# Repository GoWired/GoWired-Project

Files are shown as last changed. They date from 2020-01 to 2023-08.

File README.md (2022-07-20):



This is a repository for **GoWired**, RS485 & MySensors based, open source home automation hardware previously released at [openhardware.io](https://www.openhardware.io/user/2098#view=projects). Lately it took part in a successful **[crowdfunding campaign](https://www.crowdsupply.com/domatic/getwired)**. It is now available to buy at [Mouser](https://www2.mouser.com/Search/Refine?Keyword=getwired).

## Features
- MySensors library for communication through RS485 protocol,
- FOTW updates,
- Thermal and electrical security procedures,
- Easy configuration,
- Operating with ON/OFF receivers, roller shutters, dimmable LED tapes (white, RGB, RGBW),
- Buttons: long press and short press logic,
- Sensors: built-in current sensor and temperature sensor handling.

## Wiki
To learn more, have a look at our [wiki](https://github.com/feanor-anglin/GetWired-Project/wiki).

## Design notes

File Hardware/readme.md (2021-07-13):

All hardware schematics will be released here.

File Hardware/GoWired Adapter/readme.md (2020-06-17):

Gerber and BOM files of the Programming Adapter will be soon released here.

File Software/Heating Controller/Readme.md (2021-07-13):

Software from this folder can be used with any shield. 

This is a heating controller which is designed to control heating valves on the basis of readings from external thermometers. 
It can work with up to 8 sections. It is possible to set individual daytime temperature for every section. 
Nighttime, holiday time temperatures and hysteresis value are set for the whole module.

There are two operating methods:
- autonomous - in which the software switches outputs automatically, on the basis of comparing temperature readings with set points (it is only necessary to switch modes - day/night/holiday by an external controller)
- dependent - in which it is possible to switch outputs fron an external controller

Both methods can be switched during the controller's operation.

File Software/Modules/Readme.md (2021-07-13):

Software from this folder can be used with the following shields:
- 2SSR Shield
- RGBW Shield
- 4RelayDin Shield

It can be used for:
- Controlling lighting and other appliances (ON/OFF)
- Dimming lighting (12-24 V DC, white, RGB, RGBW)
- Controlling roller shutters (also by percentage)

Additional features
- Control board temperature (2SSR & RGBW)
- Control current (2SSR, RGBW & 4RelayDin)
- Read external thermometers: DHT22, SHT30 (2SSR, RGBW & 4RelayDin)
- Report temperature values to external Heating Controller (2SSR, RGBW & 4RelayDin)
- Read digital & analog inputs (2SSR, RGBW & 4RelayDin)
- Roller shutter auto calibration (2SSR)
- AVR watchdog

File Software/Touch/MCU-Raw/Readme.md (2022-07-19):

Firmware for Touch MCU with no wired communication functionality.

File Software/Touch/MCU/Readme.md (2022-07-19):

Firmware for Touch MCU with wired communication functionality.

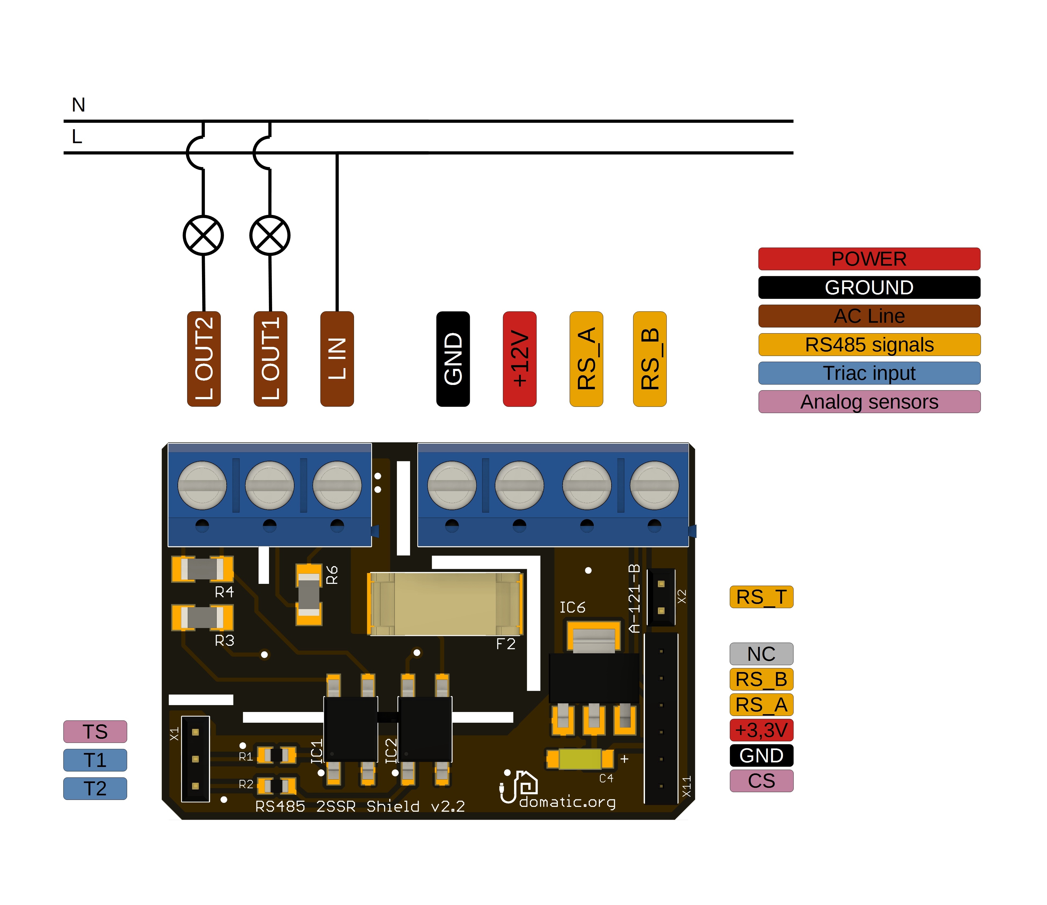
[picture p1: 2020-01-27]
Images/2SSR_Pinout_notitle.jpg

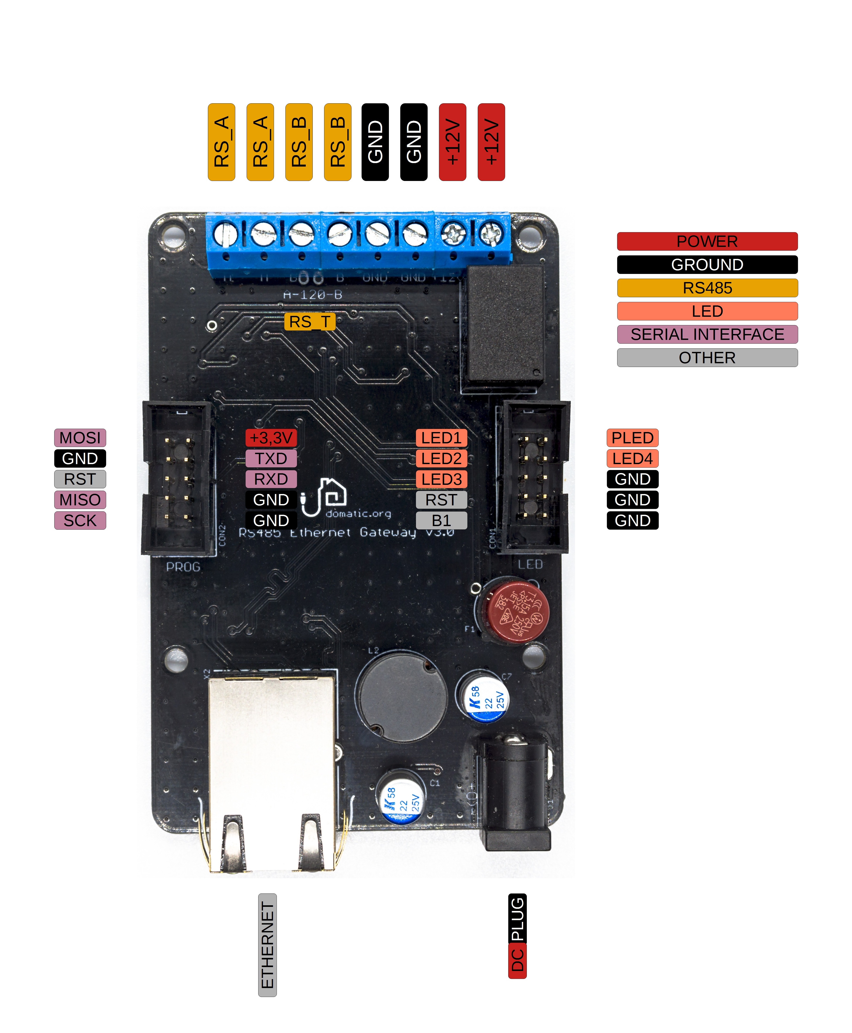
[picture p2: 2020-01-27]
Images/Gateway_Pinout_notitle.jpg

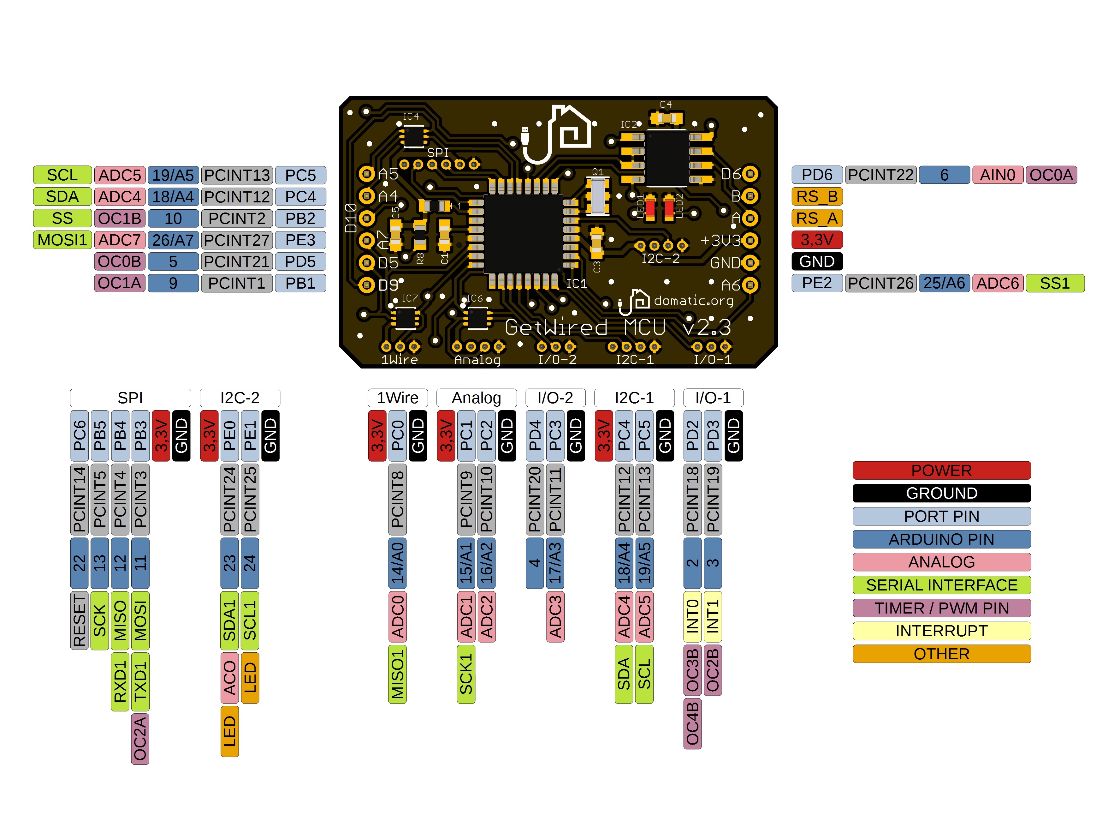
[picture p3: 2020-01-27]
Images/MCU_Pinout_notitle.jpg

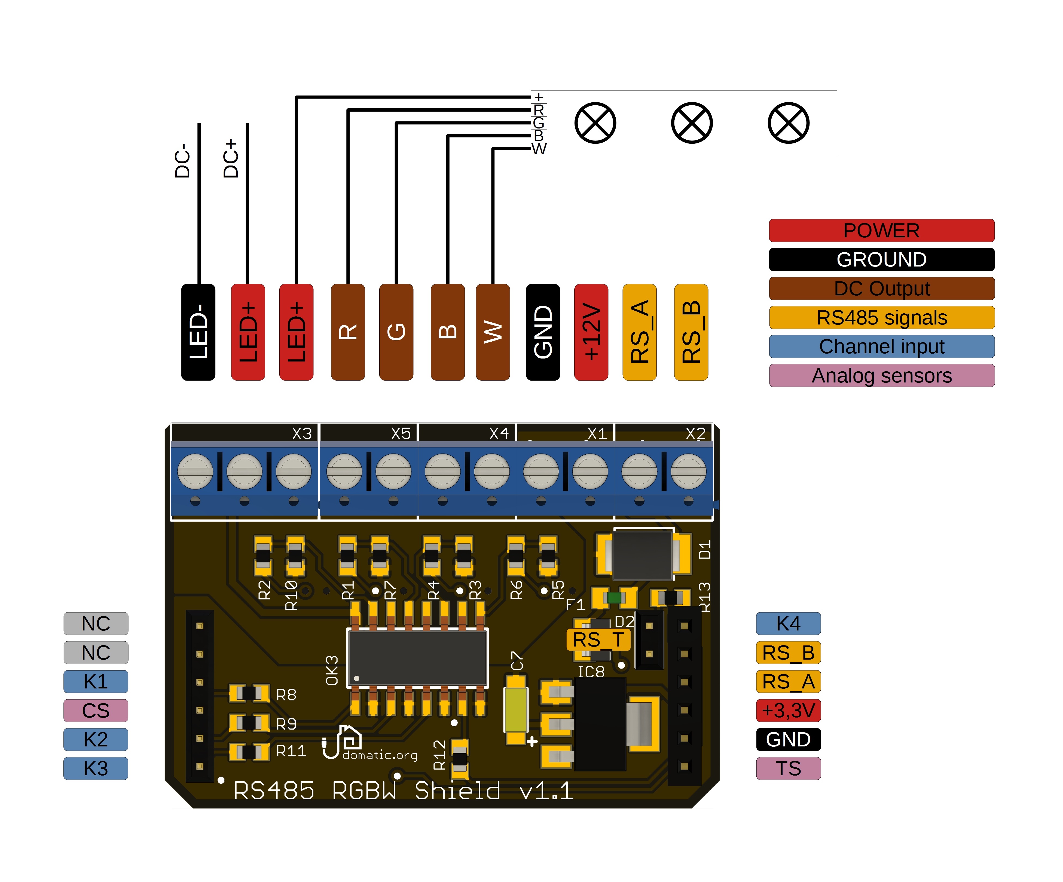
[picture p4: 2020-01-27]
Images/RGBW_Pinout_notitle.jpg

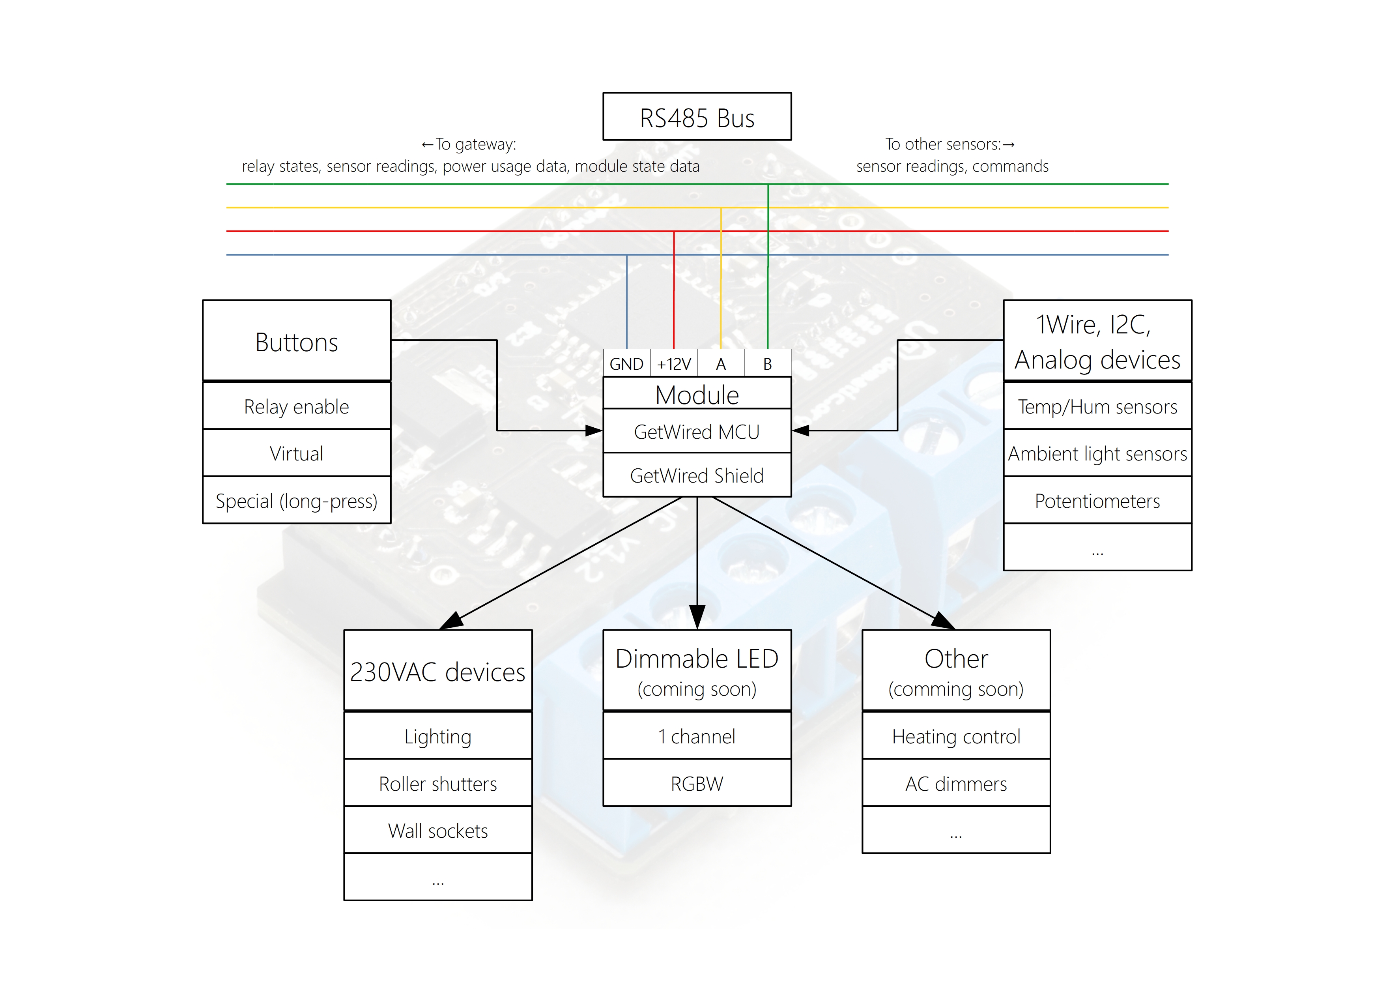
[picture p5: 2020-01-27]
Images/MCU handbook en.jpg

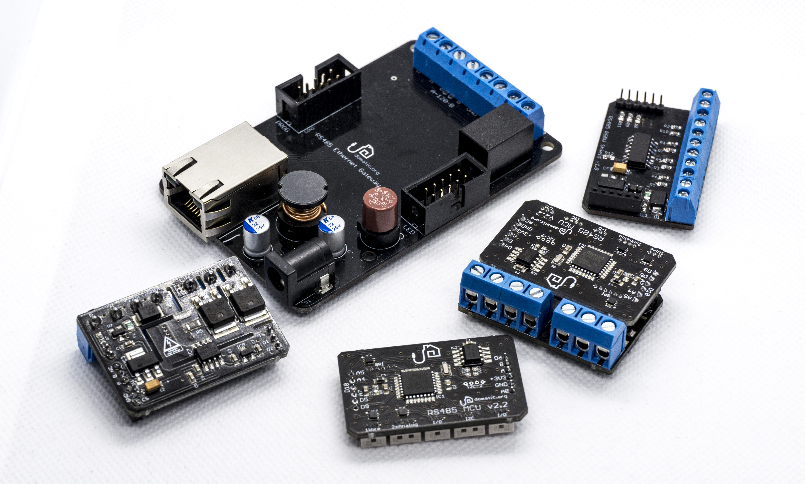
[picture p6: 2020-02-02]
Images/Gateway+modules.jpg

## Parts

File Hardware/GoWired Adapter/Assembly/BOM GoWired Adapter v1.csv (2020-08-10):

Qty | Value | Device | Package | Parts | Description | MF | MPN | OC_FARNELL | OC_NEWARK | POPULARITY | WWW
3 | 100nF | C-EUC0603 | C0603 | C1, C2, C3 | CAPACITOR, European symbol |  |  |  |  |  | https://www.tme.eu/pl/en/details/cl10b104jb8nnnc/0603-mlcc-smd-capacitors/samsung/
8 | 10k | R-EU_R0603 | R0603 | R1, R2, R3, R4, R5, R6, R7, R8 | RESISTOR, European symbol |  |  |  |  |  | https://www.tme.eu/pl/en/details/crcw060310k0jntabc/0603-smd-resistors/vishay/
1 | 1X2 | 1X2 | 1X2 | X2 |  |  | DS1025-01-1*2P8BV1-B |  |  |  | https://www.tme.eu/pl/details/zl303-02p/listwy-i-gniazda-kolkowe/connfly/ds1025-01-1-2p8bv1-b/
1 | 53047-06 | 53047-06 | 53047-06 | X1 | CONNECTOR | MOLEX | 53047-0610-C | 9733078 | 03M2965 |  | https://www.tme.eu/pl/en/details/mx-53047-0610/raster-signal-connectors-1-25mm/molex/53047-0610/
4 | BSS138 | MOSFET-NCHANNELSMD | SOT23-3 | Q1, Q2, Q3, Q4 |  |  |  |  |  |  | https://www.tme.eu/pl/en/details/bss138p.215/smd-n-channel-transistors/nexperia/
1 | DS1021-1*6SF1-1 | PINHD-1X6 | 1X06 | X4 | PIN HEADER |  |  |  |  | 79 | https://www.tme.eu/pl/details/zl201-06g/listwy-i-gniazda-kolkowe/connfly/ds1021-1-6sf1-1/
1 | LD1117S33C | REG1117 | SOT223 | IC1 | 800mA and 1A Low Dropout (LDO) Positive Regulator |  | LD1117S33C | 1097566 | 14P6981 |  | https://www.tme.eu/pl/en/details/ld1117s33c/ldo-unregulated-voltage-regulators/stmicroelectronics/
1 | T821110A1S100CEU | CON10L | CON10L | X3 | CONNECTOR |  |  | unknown | unknown |  | https://www.tme.eu/pl/en/details/t821-1-10-s1/idc-connectors/amphenol/t821110a1s100ceu/

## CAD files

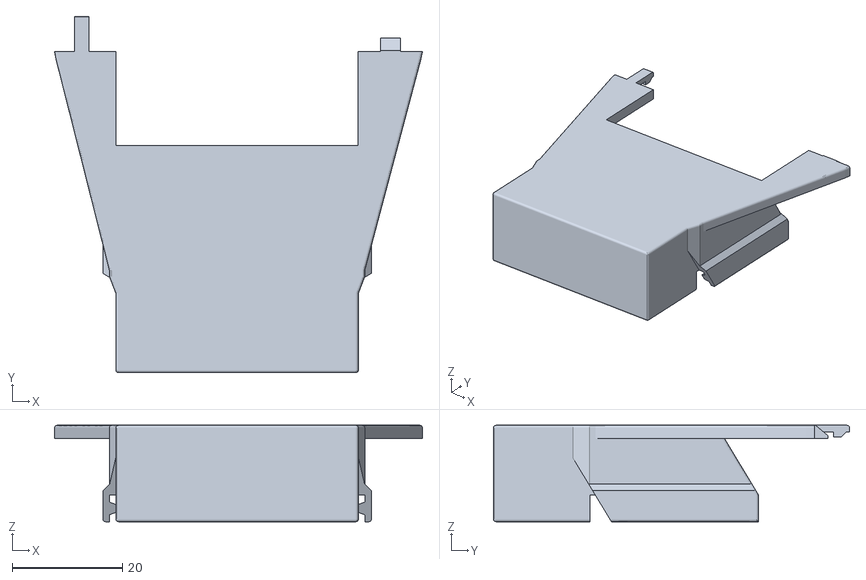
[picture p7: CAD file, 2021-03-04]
Enclosures/In-Wall-to-DIN_top.stl
66.7 x 64.6 x 17.5

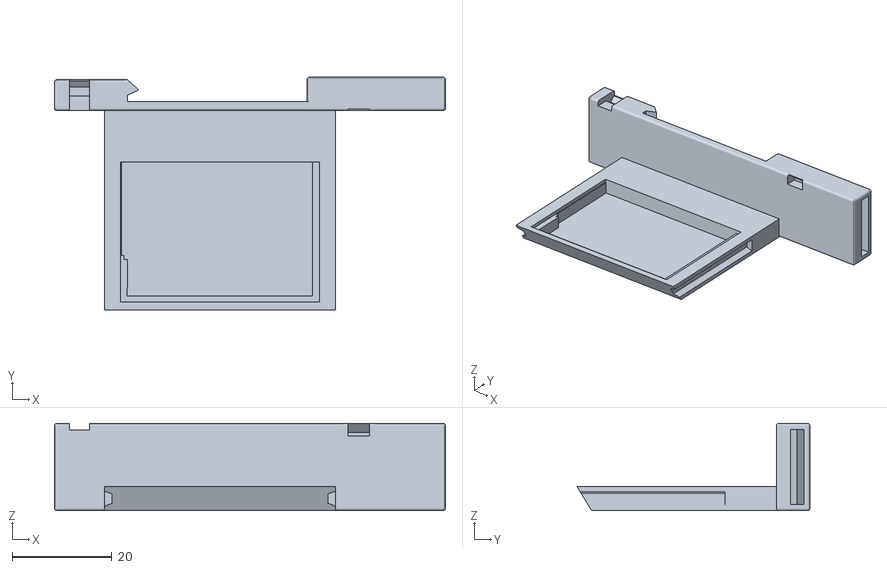
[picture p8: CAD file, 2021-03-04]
Enclosures/In-Wall-to-DIN_bot.stl
78.3 x 46.7 x 17.5

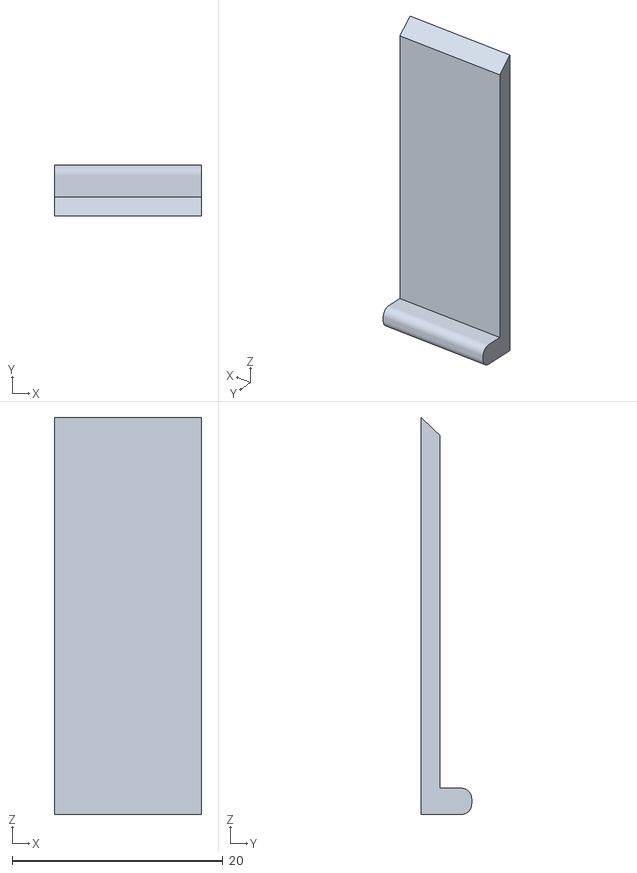
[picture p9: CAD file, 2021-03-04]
Enclosures/DIN Rail Pin.stl
14.0 x 4.80 x 37.7

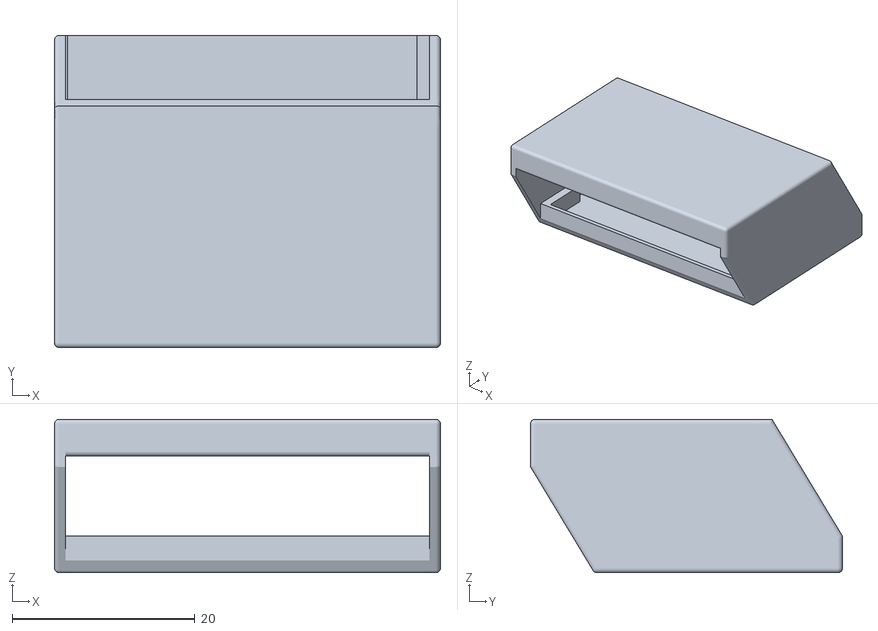
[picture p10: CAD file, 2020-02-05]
Enclosures/GoWired In-wall Case.stl
42.3 x 34.2 x 16.8

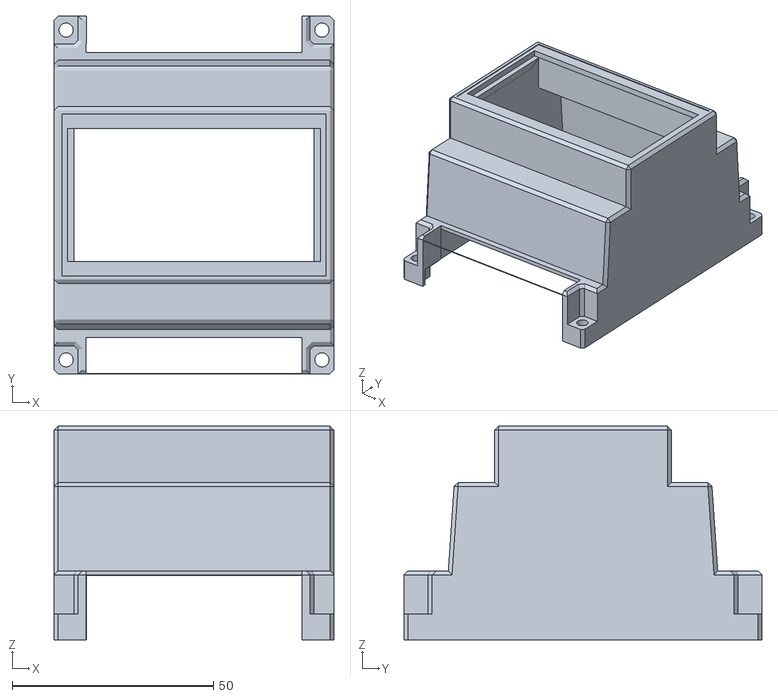
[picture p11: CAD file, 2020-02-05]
Enclosures/GoWired DIN Rail Case top.stl
69.6 x 89.0 x 53.2

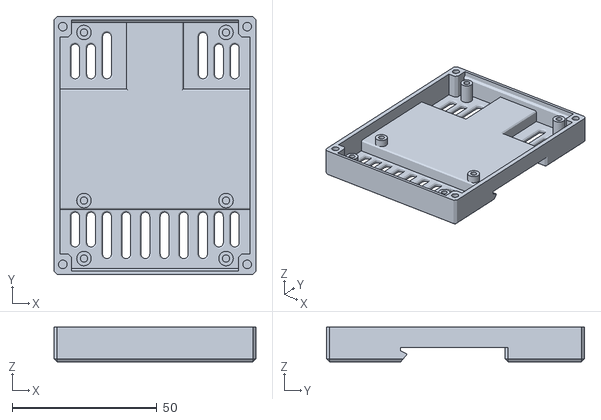
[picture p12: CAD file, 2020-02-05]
Enclosures/GoWired DIN Rail Case bottom.stl
69.6 x 89.0 x 12.0

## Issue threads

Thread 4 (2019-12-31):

link from the documentation is not working. Typp

anikiej, 2019-12-31:
->Tis<- is software for GetWired Home Automation Modules by Domatic, open home automation hardware previously released at >>>openhardware.io<<< (page not working).

feanor-anglin, 2020-01-02:
This is an openhardware.io related issue. All profiles on openhardware are currently inaccessible. I will ask them for support. Thank you for reporting.

feanor-anglin, 2020-01-07:
Page is online again.

Closed 2020-01-07.

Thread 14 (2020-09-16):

Can't compile Gateway-MQTT project

Lama1121, 2020-09-16:
I'm getting following error when compiling Gateway-MQTT
_Arduino: 1.8.13 (Windows 10), Board: "ATmega328, No bootloader, EEPROM retained, 328PB, BOD 2.7V, LTO disabled, External 8 MHz"_

_c:/rob/arduino-1.8.13/hardware/tools/avr/bin/../lib/gcc/avr/7.3.0/../../../../avr/bin/ld.exe: C:\Users\WJCWSM~1.EUR\AppData\Local\Temp\arduino_build_885427/Gateway-MQTT.ino.elf section `.data' will not fit in region `text'_

_c:/rob/arduino-1.8.13/hardware/tools/avr/bin/../lib/gcc/avr/7.3.0/../../../../avr/bin/ld.exe: region `text' overflowed by 70 bytes_

_collect2.exe: error: ld returned 1 exit status_

_exit status 1_

_Error compiling for board ATmega328._
Using UIPEthernet version 2.0.9
and MySensors version 2.3.2

feanor-anglin, 2020-09-22:
Please enable LTO, it should help.

Closed 2020-10-12.

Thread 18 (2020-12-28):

Missing SHTSensor.h

kolczak, 2020-12-28:
`GetWired New Firmware/main.ino` file contains
```
#include "SHTSensor.h"
```
I can't find this file anywhere. Should that include be removed?

feanor-anglin, 2020-12-29:
All libraries needed to compile are [here](https://github.com/feanor-anglin?tab=repositories). The library for SHT sensor should also be there, but of course you can remove this include if you are not willing to use any SHT sensors.

Closed 2020-12-29.

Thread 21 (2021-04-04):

how to ota

WangChun420, 2021-04-04:
I see the define MY_OTA_FIRMWARE_FEATURE - enables firmware-over-the-wire updates (defined by default)，but how to?is there use some other bootloader?

feanor-anglin, 2021-04-06:
We have not yet documented this feature on our wiki, because it is not entirely ready. It is possible, though there is a bootloader problem - code has to be compiled for Sensebender Micro hardware package for Arduino IDE, and Dualoptiboot bootloader has to be used. But, you won't be able to flash firmware to MCU with this settings, you will have to use AVRDUDE. Also, have a look at [this article](https://www.mysensors.org/about/fota).

Closed 2021-04-08.

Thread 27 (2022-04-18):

Upgrade to 1.3.0 failed for some modules

djvl, 2022-04-18:
Today I spend some time to upgrade the software on some MCU modules (2SSR & RGBW) from 1.2.0 to the new 1.3.0 release but had to roll back to 1.2.0 because of restarting node issues. It appeared to be an issue with the digital inputs, as soon as I disabled the PIRs connected to the inputs the restarting issue went away. I did not had the time to dig deeper, but will try to have another look at it soon. Any idea how to troubleshoot this kind of issue? I am using a MQTT enabled gateway.

feanor-anglin, 2022-04-19:
1.3.0 uses entirely different code for reading inputs, so your feedback is truly valuable to me. I am already aware of some issues when using it with security sensors. Some improvements has already been developed, so if you give me a few days, I should come up with a fix. In the meantime, could you give me some more details of what exactly you use, how is it connected and configured?

djvl, 2022-04-19:
Sure, no problem. I will describe one of the failing nodes in more detail about how it is setup. First of all on the hardware side. The MCU module (1.0) is used in combination with a 2SSR shield. The PIR (Satel Aqua Ring 12v) is connected to an external 12v power source and the signal cable (2x NC) is connected to the MCU I/O-2 (I/O-1 is not yet being used on this node).

I/O-2 Arduino PIN4 (yellow cable) to NC on PIR
I/O-2 GND (red cable) to NC on PIR

On the software side I like to follow the defaults as much as possible. To prevent any upgrade issues I chose to use the ‘Configuration.h’ which comes with the new release and change only the MY_NODE_ID, SN, SV (was 1.2 on the 1.3 release) and dependent on the module one of the following: DOUBLE_RELAY, DIMMER or RGBW. In this case it is  DOUBLE_RELAY.

If there is more you want me to check or test, please let me know.

feanor-anglin, 2022-04-20:
@djvl thank you for your cooperation. I've pushed a fix to dev branch, could you test it and post me the result? It works for me on a slightly different hardware. If you are using your modules with PIR sensors you may want to invert input logic in Configuration.h:
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
Simply change _false_ to _true_ next to the _INVERT_X_ parameter.

djvl, 2022-04-20:
@feanor-anglin I can confirm the fix works for me as well. Thank you for your quick response and solution. I will try the suggestion about the invert logic when I have more time as it will also involve a change on my controller. Thanks again!

Closed 2022-04-20.

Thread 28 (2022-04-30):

Power sensor reports unexpeced value

djvl, 2022-04-30:
I am using openHAB as home automation controller in combination with GoWired and receive events over MQTT. Since I have added the topics for power and error readings the openHAB logging started to show the following warnings:

[WARN ] [ab.binding.mqtt.generic.ChannelState] - Incoming payload ' 0' not supported by type 'NumberValue'

It appears to be an issue with the power reading as can be seen on the following mosquitto_sub logging:
```
gwo/7/9/1/0/17 30
gwo/7/9/1/0/17  0  <-- there is a leading space in front of the 0
```
When for instance the lighting is turned off the reported value goes to ' 0' where I expected it to be '0'.

Is this intended or a bug?

feanor-anglin, 2022-05-01:
Hi @djvl, thanks for posting. I can't see any reason for such behavior. This is the line, that sends power value to the controller:
```
send(msgPS.set(PS.CalculatePower(Current, COSFI), 0));
```
_PS.CalculatePower()_ returns float. So it seems it is related to MySensors or MQTT.

djvl, 2022-05-02:
Okay, I see. I will have a look at both MySensors and MQTT. If I come across a solution I will report back.

Closed 2022-05-02.

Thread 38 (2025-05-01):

Ethernet Gateway does not stay running

bferrell, 2025-05-01:
I've flashed the chip with a USBasp and can ping to board for about 30 seconds.  Then responses stop?
Suggestions?

feanor-anglin, 2025-05-06:
Hello! Do you have any type of controller (e. g. Home Assistant) connected to the gateway? The software automatically checks for connection then reboots the module to prevent connectivity issues. You can always deactivate this feature.

Just comment out
`#define ENABLE_UPLINK_CHECK`
to turn it off.

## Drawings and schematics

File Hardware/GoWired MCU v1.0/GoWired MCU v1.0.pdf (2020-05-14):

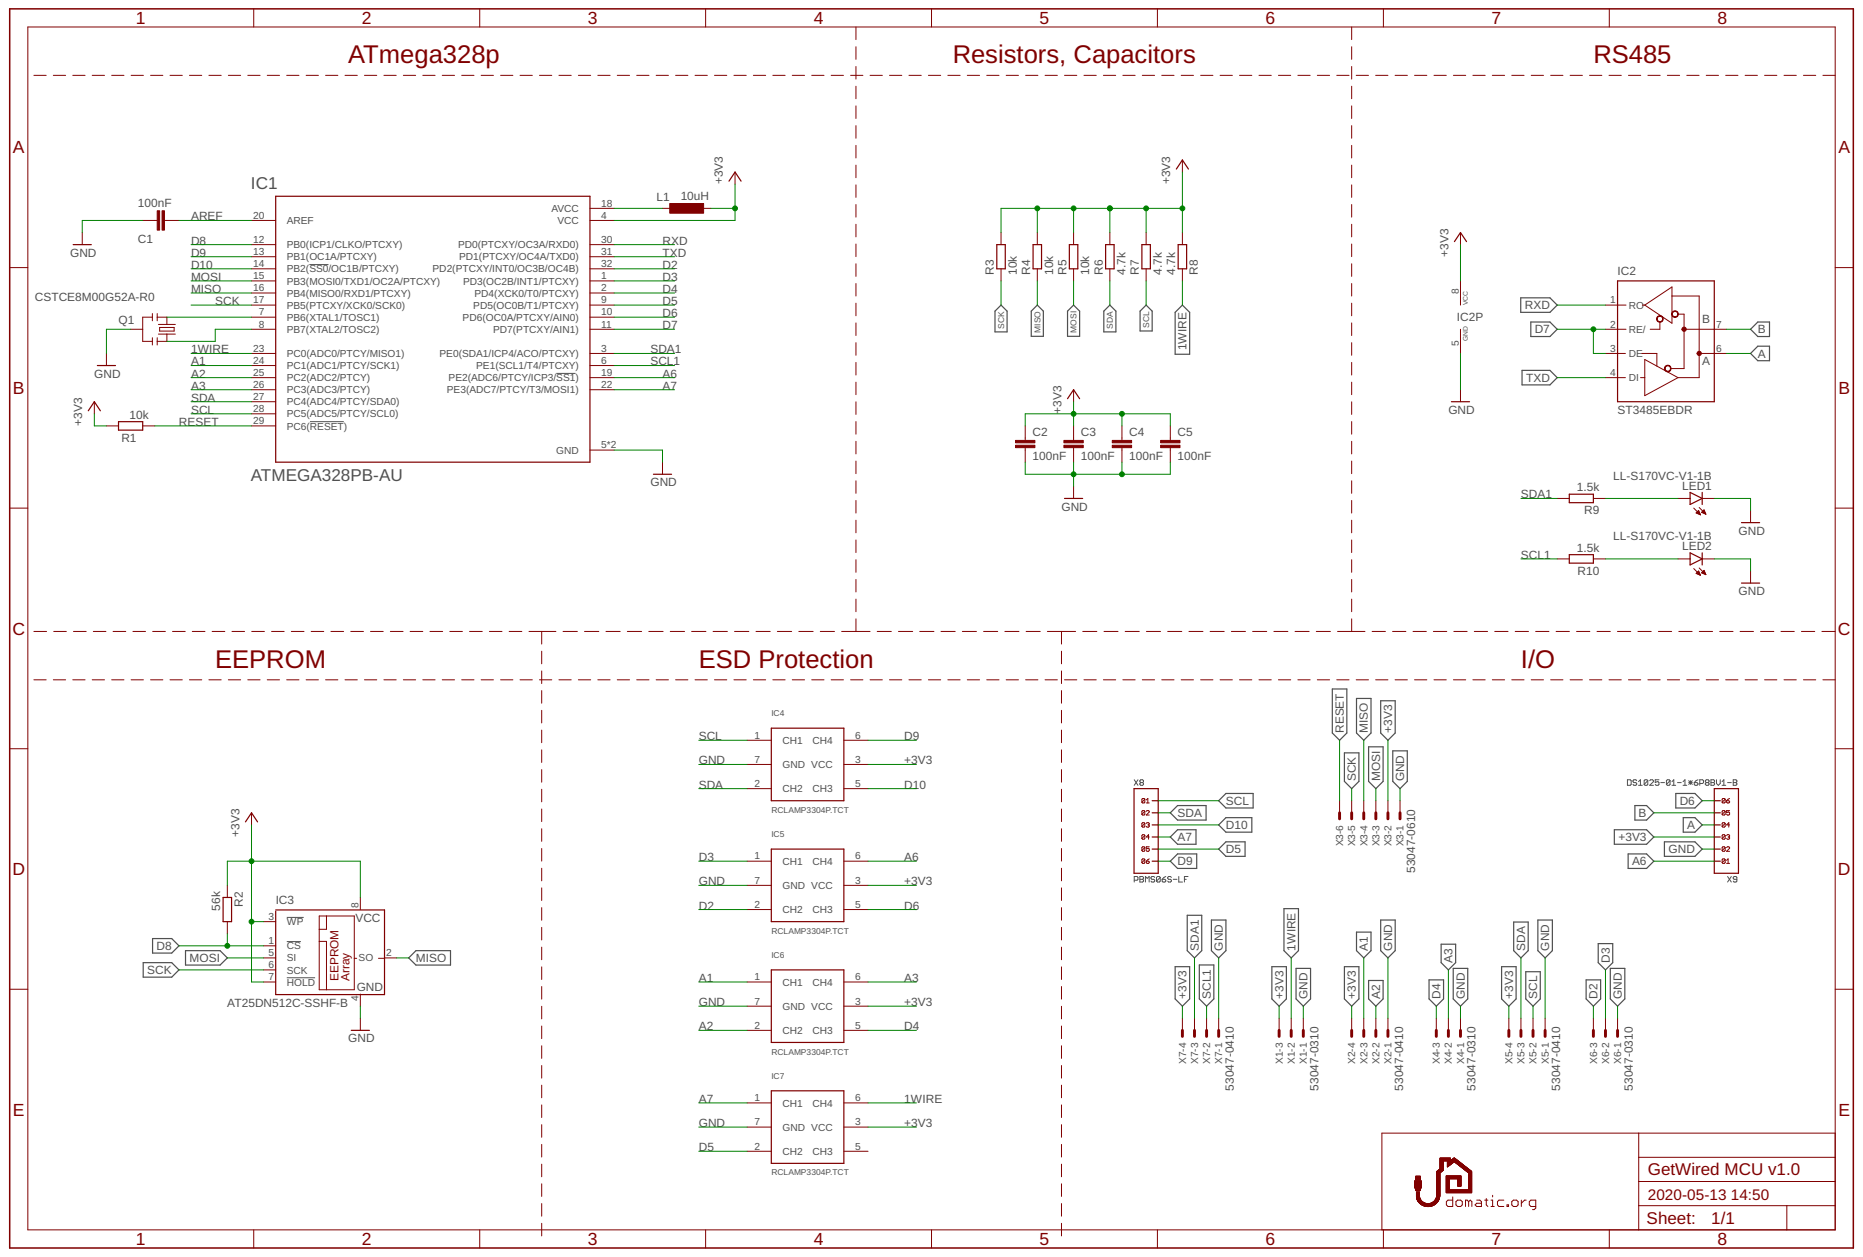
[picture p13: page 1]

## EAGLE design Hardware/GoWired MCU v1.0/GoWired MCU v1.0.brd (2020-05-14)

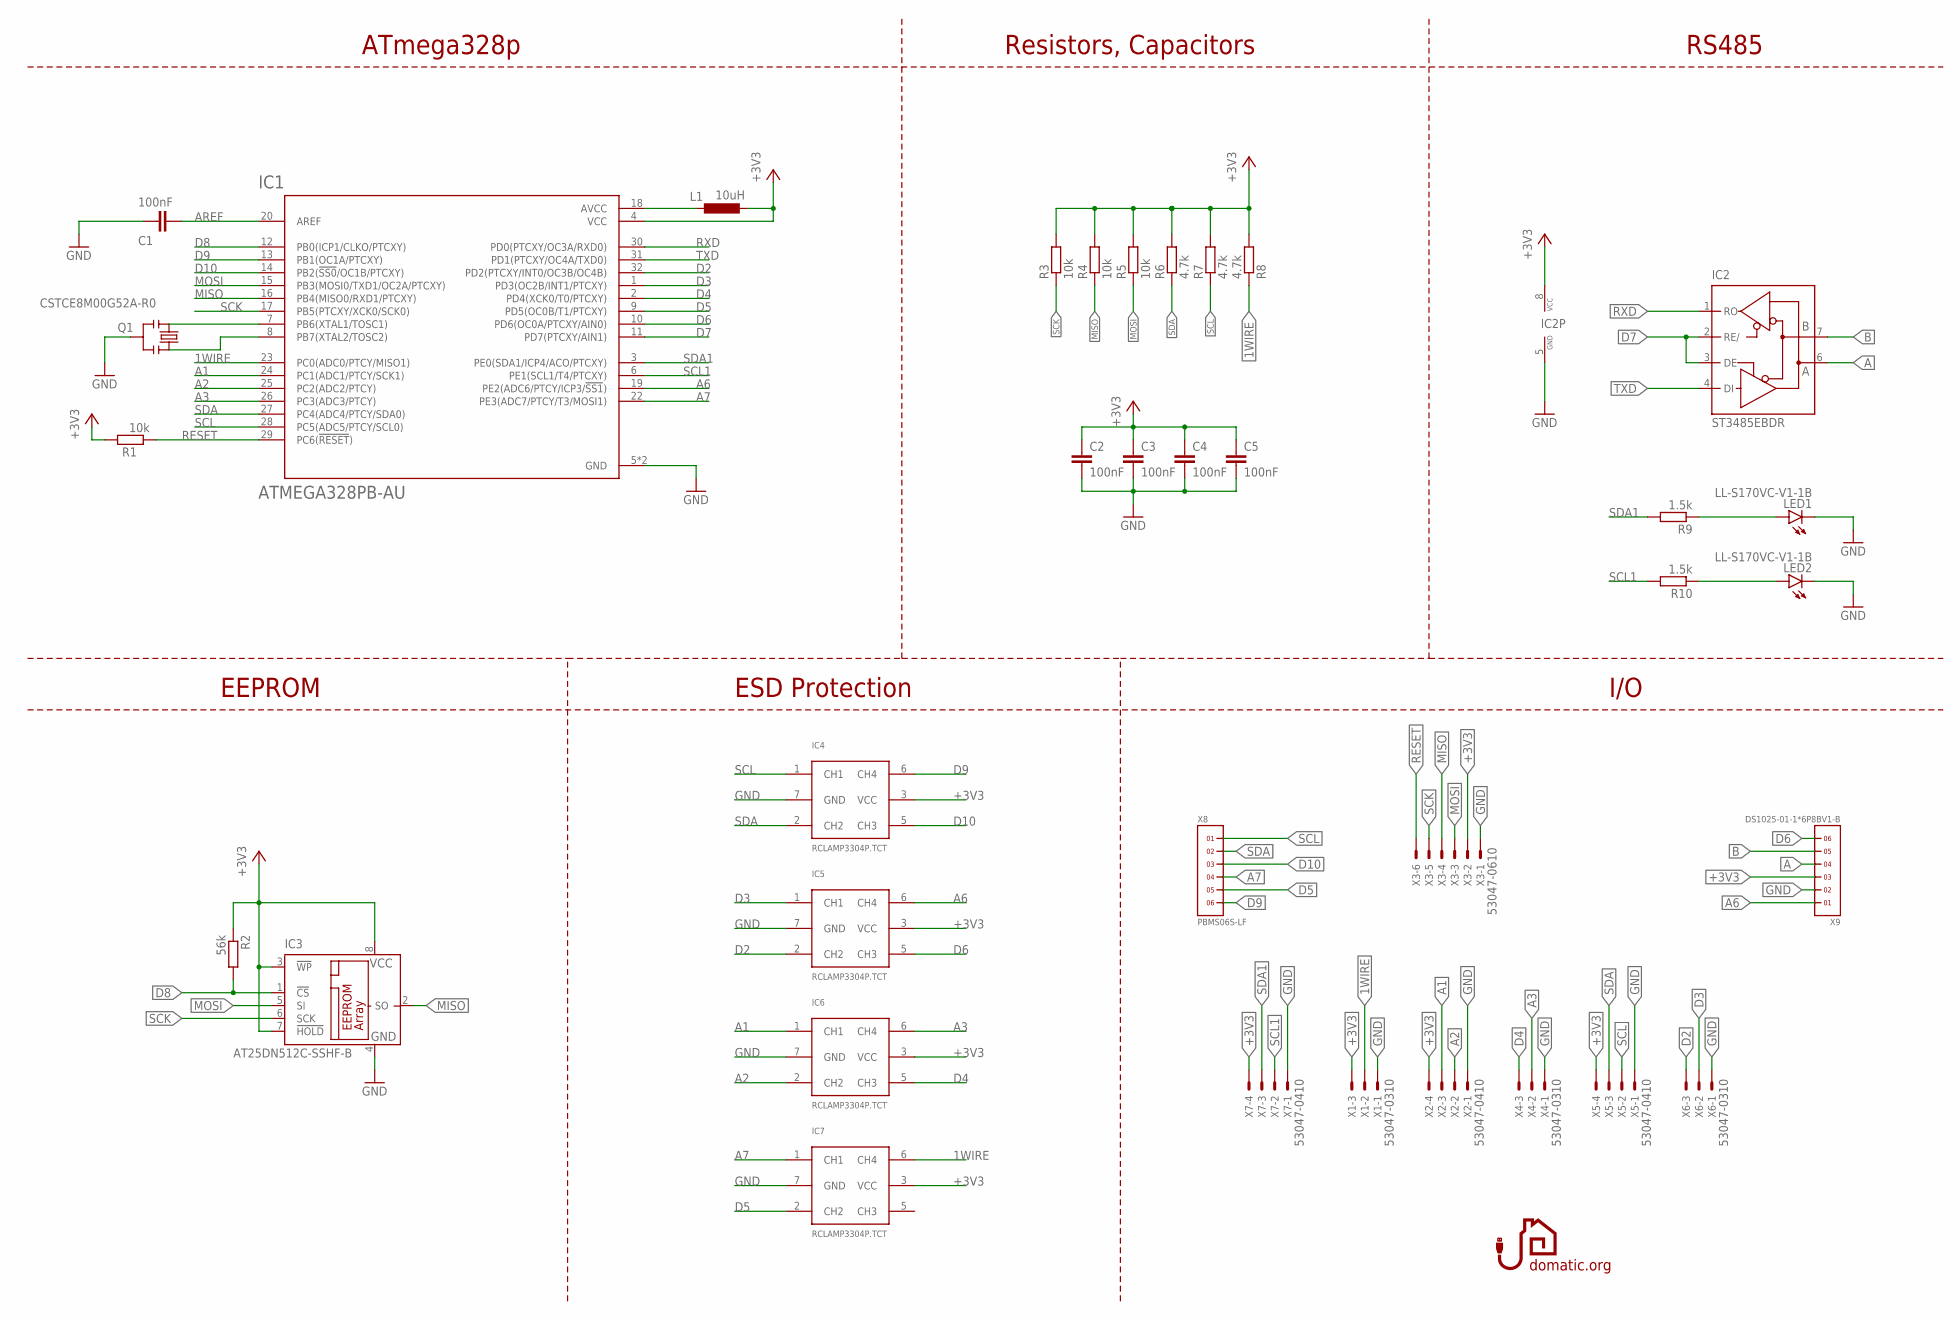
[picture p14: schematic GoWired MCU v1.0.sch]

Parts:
C1, C2, C3, C4, C5: 100nF; C0603
IC1: ATMEGA328PB-AU; TQFP32-08-REF
IC2: ST3485EBDR; SO08; MPN ST3485EBDR
IC3: AT25DN512C-SSHF-B; SO-08; MPN AT25DN512C-SSHF-B
IC4, IC5, IC6, IC7: RCLAMP3304P.TCT; SON50P160X160X65-7T45X130-V2
L1: 10uH; C1608
LED1, LED2: LL-S170VC-V1-1B; CHIPLED_0603
Q1: CSTCE8M00G52A-R0; CSTCE_V_C
R1, R3, R4, R5: 10k; R0603
R2: 56k; R0603
R6, R7, R8: 4.7k; R0603
R9, R10: 1.5k; R0603
X1, X4, X6: 53047-0310; 53047-03
X2, X5, X7: 53047-0410; 53047-04
X3: 53047-0610; 53047-06
X8: PBMS06S-LF; 1X6-FEMALE-LONG
X9: DS1025-01-1*6P8BV1-B; HDRV6W50P200_1X6_1200X200X600B

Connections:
1WIRE: IC1.23 (PC0(ADC0/PTCY/MISO1)), IC7.6 (CH4), R8.1, X1.2
+3V3: C2.2, C3.2, C4.1, C5.1, IC1.4 (VCC), IC2.8 (VCC), IC3.3 (!WP), IC3.7 (!HOLD), IC3.8 (VCC), IC4.3 (VCC), IC5.3 (VCC), IC6.3 (VCC), IC7.3 (VCC), L1.1, R1.2, R2.1, R3.2, R4.2, R5.2, R6.2, R7.2, R8.2, X1.3, X2.4, X3.2, X5.4, X7.4, X9.3
A: IC2.6 (A), X9.4
A1: IC1.24 (PC1(ADC1/PTCY/SCK1)), IC6.1 (CH1), X2.3
A2: IC1.25 (PC2(ADC2/PTCY)), IC6.2 (CH2), X2.2
A3: IC1.26 (PC3(ADC3/PTCY)), IC6.6 (CH4), X4.2
A6: IC1.19 (PE2(ADC6/PTCY/ICP3/!SS1!)), IC5.6 (CH4), X9.1
A7: IC1.22 (PE3(ADC7/PTCY/T3/MOSI1)), IC7.1 (CH1), X8.4
AREF: C1.2, IC1.20 (AREF)
B: IC2.7 (B), X9.5
D2: IC1.32 (PD2(PTCXY/INT0/OC3B/OC4B)), IC5.2 (CH2), X6.3
D3: IC1.1 (PD3(OC2B/INT1/PTCXY)), IC5.1 (CH1), X6.2
D4: IC1.2 (PD4(XCK0/T0/PTCXY)), IC6.5 (CH3), X4.3
D5: IC1.9 (PD5(OC0B/T1/PTCXY)), IC7.2 (CH2), X8.5
D6: IC1.10 (PD6(OC0A/PTCXY/AIN0)), IC5.5 (CH3), X9.6
D7: IC1.11 (PD7(PTCXY/AIN1)), IC2.2 (RE/), IC2.3 (DE)
D8: IC1.12 (PB0(ICP1/CLKO/PTCXY)), IC3.1 (!CS), R2.2
D9: IC1.13 (PB1(OC1A/PTCXY)), IC4.6 (CH4), X8.6
D10: IC1.14 (PB2(!SS0!/OC1B/PTCXY)), IC4.5 (CH3), X8.3
GND: C1.1, C2.1, C3.1, C4.2, C5.2, IC1.5 (GND), IC1.21 (GND), IC2.5 (GND), IC3.4 (GND), IC4.7 (GND), IC5.7 (GND), IC6.7 (GND), IC7.7 (GND), LED1.C, LED2.C, Q1.GND, X1.1, X2.1, X3.1, X4.1, X5.1, X6.1, X7.1, X9.2
MISO: IC1.16 (PB4(MISO0/RXD1/PTCXY)), IC3.2 (SO), R4.1, X3.4
MOSI: IC1.15 (PB3(MOSI0/TXD1/OC2A/PTCXY)), IC3.5 (SI), R5.1, X3.3
unnamed: LED1.A, R9.1
unnamed: IC1.7 (PB6(XTAL1/TOSC1)), Q1.X1
unnamed: IC1.8 (PB7(XTAL2/TOSC2)), Q1.X2
unnamed: IC1.18 (AVCC), L1.2
unnamed: LED2.A, R10.1
RESET: IC1.29 (PC6(!RESET!)), R1.1, X3.6
RXD: IC1.30 (PD0(PTCXY/OC3A/RXD0)), IC2.1 (RO)
SCK: IC1.17 (PB5(PTCXY/XCK0/SCK0)), IC3.6 (SCK), R3.1, X3.5
SCL: IC1.28 (PC5(ADC5/PTCY/SCL0)), IC4.1 (CH1), R7.1, X5.2, X8.1
SCL1: IC1.6 (PE1(SCL1/T4/PTCXY)), R10.2, X7.2
SDA: IC1.27 (PC4(ADC4/PTCY/SDA0)), IC4.2 (CH2), R6.1, X5.3, X8.2
SDA1: IC1.3 (PE0(SDA1/ICP4/ACO/PTCXY)), R9.2, X7.3
TXD: IC1.31 (PD1(PTCXY/OC4A/TXD0)), IC2.4 (DI)

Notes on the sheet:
ATmega328p
I/O
EEPROM
RS485
Resistors, Capacitors
ESD Protection

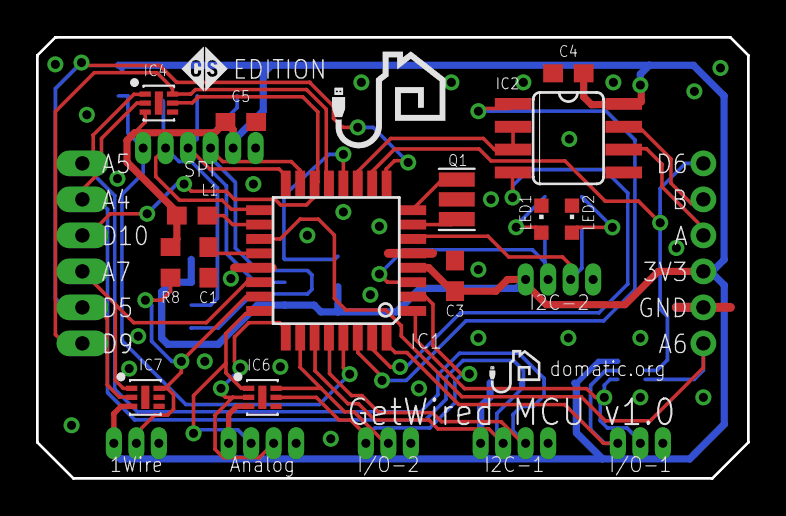
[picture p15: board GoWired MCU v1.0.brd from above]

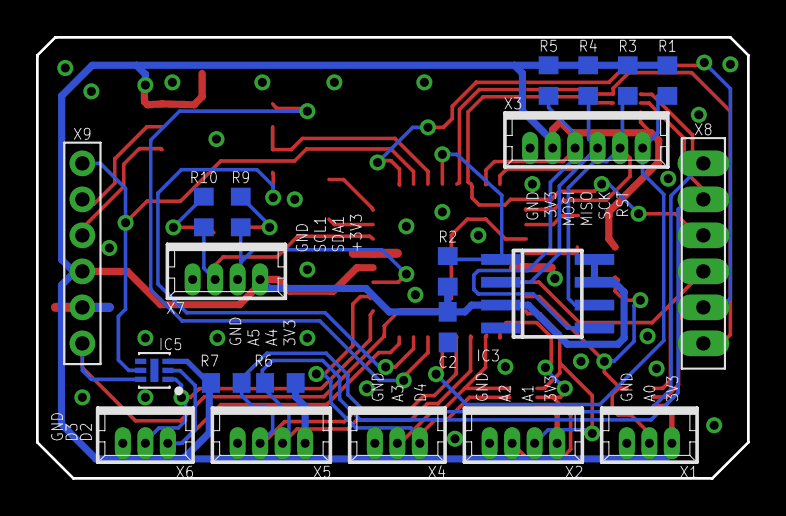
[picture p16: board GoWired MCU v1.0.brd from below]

Board: 2 copper layers, 39.5 x 24.5 mm, 38 parts (21 on the bottom side), 35 nets.

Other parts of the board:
U$1: CS2-2.5MM
U$2: LOGO5MMBEZ
U$3: LOGO2.5MMNAP0,8

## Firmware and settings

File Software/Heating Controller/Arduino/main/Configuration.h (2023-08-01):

/*
 * 
 * All definitions in one file
 * 
 */


#ifndef Configuration_h
#define Configuration_h

/*  *******************************************************************************************
 *                            MySensors Definitions
 *  *******************************************************************************************/
// Identification
#define MY_NODE_ID AUTO
#define SN "GW-HC"
#define SV "2.1"

// Selecting transmission settings
#define MY_RS485                              // Enable RS485 transport layer
#define MY_RS485_DE_PIN 7                     // DE Pin definition
#define MY_RS485_BAUD_RATE 57600              // Set RS485 baud rate to use
#define MY_RS485_HWSERIAL Serial              // Enable for Hardware Serial
#define MY_RS485_SOH_COUNT 3                  // Collision avoidance

// FOTA Feature
#define MY_OTA_FIRMWARE_FEATURE

// Other
#define MY_TRANSPORT_WAIT_READY_MS 60000      // Time to wait for gateway to respond at startup

/*  *******************************************************************************************
 *                                      Various Definitions
 *  *******************************************************************************************/
// Shield - choose only 1
// Define this if your shield utilizes an I2C Expander (Heating Shield, I/O Shield, etc.)
#define EXPANDER_SHIELD
#define EXPANDER_ADDRESS 0x20

// Define this if your shield controls outputs directly, by uC pins (2SSR Shield - up to 2 sections, 4RelayDin Shield - up to 4 sections)                                 
//#define DIRECT_SHIELD                                 

// Relays
#define RELAY_ON HIGH
#define RELAY_OFF LOW

// Sections and setpoints
#define HEATING_SECTIONS 8                              // Number of heating sections (default 8, available 1-8)
#define DEFAULT_DAY_SP 20                               // Default day setpoint temperature (default 20)
#define DEFAULT_NIGHT_SP 18                           // Default night setpoint (default 18)
#define DEFAULT_HOLIDAY_SP 10                         // Default holiday setpoint (default 10)
#define DEFAULT_HYSTERESIS 0                            // Default hysteresis (default 0)
   
// IDs
#define FIRST_SECTION_ID 0                              // Sensor ID of first section
#define SELECTOR_SWITCH_ID FIRST_SECTION_ID+HEATING_SECTIONS           // Selector switch ID: ON/OFF / Day/Night/Holiday
#define SPN_ID SELECTOR_SWITCH_ID+1                     // Night set point ID (one for all sections)
#define SPH_ID SPN_ID+1                                 // Holiday set point ID (one for all sections)
#define HYSTERESIS_ID SPH_ID+1                          // Hysteresis ID

// Section temperature sensors IDs
#define T_ID_1 31                     
#define T_ID_2 35
#define T_ID_3 37
#define T_ID_4 38
#define T_ID_5 40
#define T_ID_6 51
#define T_ID_7 52
#define T_ID_8 53

// I2C Sensors
//#define INTERNAL_TEMP
#ifdef INTERNAL_TEMP
  #define ITT_ID HYSTERESIS_ID+1
  #define ITH_ID ITT_ID+1
  #define IT_STATUS_ID ITH_ID+1
#endif

// Main loop definitions
#define INTERVAL 300000                    // Interval value for reporting readings of the sensors: temperature, power usage (default 300000)
#define INIT_DELAY 200                       // A value to be multiplied by node ID value to obtain the time to wait during the initialization process
#define PRESENTATION_DELAY 10       // Time (ms) to wait between subsequent presentation messages (default 10)
#define LOOP_TIME 5000                       // Main loop wait time (default 100)        

/*  *******************************************************************************************
 *                                   MCU Pin Definitions
 *  *******************************************************************************************/
// OUTPUT [RELAY / RGBW]
#define OUTPUT_PIN_1 5
#define OUTPUT_PIN_2 9
#define OUTPUT_PIN_3 6
#define OUTPUT_PIN_4 10

// INPUT [BUTTON / SENSOR]
// General input
#define INPUT_PIN_1 2
#define INPUT_PIN_2 3
#define INPUT_PIN_3 4
#define INPUT_PIN_4 A3

// Analog input
#define INPUT_PIN_5 A1
#define INPUT_PIN_6 A2
#define INPUT_PIN_7 A6
#define INPUT_PIN_8 A7

// Protocols
// 1-wire
#define ONE_WIRE_PIN A0

// I2C
#define I2C_PIN_1 A4
#define I2C_PIN_2 A5

/*  *******************************************************************************************
 *                                   ERROR REPORTING
 *  *******************************************************************************************/
#define ERROR_REPORTING
#ifdef ERROR_REPORTING
  #ifdef POWER_SENSOR
    #define ES_ID HYSTERESIS_ID+1
  #endif
  #ifdef INTERNAL_TEMP
    #define TS_ID ES_ID+1
  #endif
  #ifdef EXTERNAL_TEMP
    #define ETS_ID TS_ID+1
  #endif
#endif

//#define RS485_DEBUG
#ifdef RS485_DEBUG
  #define DEBUG_ID ETS_ID+1
#endif

/*  *******************************************************************************************
 *                                  EEPROM Definitions
 *  *******************************************************************************************/
#define SIZE_OF_BYTE 1
#define SIZE_OF_FLOAT 4
#define EEPROM_OFFSET 512                     // First eeprom address to use (MySensors uses prior addresses)
#define EA_HM EEPROM_OFFSET                   // EEPROM address to save Heating Mode value (byte)
#define EA_SPN EA_HM+SIZE_OF_BYTE             // EEPROM address to save thermostat value for night mode (float)
#define EA_SPH EA_SPN+SIZE_OF_FLOAT           // EEPROM address to save thermostat value for holiday mode (float)
#define EA_HYSTERESIS EA_SPH+SIZE_OF_FLOAT    // EEPROM address to save hysteresis value (float)
#define EA_FIRST_SECTION EA_HYSTERESIS+SIZE_OF_FLOAT  // EEPROM address to save section values (float)

 
#endif
/*
 * 
 * EOF
 * 
 */

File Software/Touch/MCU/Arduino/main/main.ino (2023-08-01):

/*
 * GoWired is an open source project for WIRED home automation. It aims at making wired
 * home automation easy and affordable for every home automation enthusiast. GoWired provides
 * hardware, software, enclosures and instructions necessary to build your own bus communicating
 * smart home installation.
 * 
 * GoWired is based on RS485 industrial communication standard. The software uses MySensors
 * communication protocol (http://www.mysensors.org). 
 *
 * Created by feanor-anglin
 * Copyright (C) 2018-2022 feanor-anglin
 *
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
 * ******************************
 * This is source code for GoWired Touch MCU boards working with 2Relay or RGBW shields.
 * 
 */

/***** INCLUDES *****/
#include "Configuration.h"
#include <GoWired.h>
#include <LP50XX.h>
#ifdef SHT30
  #include <SHTSensor.h>
#endif

/***** Globals *****/
// General
// 0 - 2Relay; 1 - RGBW
uint8_t HardwareVariant;
// HardwareVariant = 0: LoadVariant=> 0 - 1 relay; 1 - 2 relays; 2 - roller shutter
// HardwareVariant = 1: LoadVariant=> 0 - rgb; 1 - rgbw; 2 - 1-channel dimmer
uint8_t LoadVariant;
uint8_t Iterations;

// Shutter
uint32_t MovementTime;
uint32_t StartTime;

// Timer
uint32_t LastUpdate = 0;               // Time of last update of interval sensors
bool CheckNow = true;

// Module Safety Indicators
bool OVERCURRENT_ERROR = false;            // Overcurrent error status
bool InformControllerES = false;            // Was controller informed about error?
bool ET_ERROR = 0;                       // External thermometer status (0 - ok, 1 - error)

// Initialization
bool InitConfirm = false;

// Touch Diagnosis
uint8_t LimitTransgressions = 0;
uint8_t LongpressDetection = 0;

/***** Constructors *****/
// LP5009 - onboard RGB LED controller
LP50XX LP5009(BGR, LP5009_ENABLE_PIN);

// CommonIO constructor
CommonIO CommonIO[NUMBER_OF_RELAYS+NUMBER_OF_INPUTS];

// Shutter Constructor
Shutters Shutter(EEA_SHUTTER_TIME_DOWN, EEA_SHUTTER_TIME_UP, EEA_SHUTTER_POSITION);

// Dimmer class constructor
Dimmer Dimmer;

// Power sensor class constructor
#ifdef POWER_SENSOR
  PowerSensor PS;
  MyMessage MsgWATT(0, V_WATT);
#endif

// SHTSensor class constructor
#ifdef SHT30
  SHTSensor sht;
  MyMessage MsgTEMP(0, V_TEMP);
  MyMessage MsgHUM(0, V_HUM);
#endif

// Protocol messages constructors
MyMessage MsgSTATUS(0, V_STATUS);
MyMessage MsgUP(0, V_UP);
MyMessage MsgDOWN(0, V_DOWN);
MyMessage MsgSTOP(0, V_STOP);
MyMessage MsgPERCENTAGE(0, V_PERCENTAGE);
MyMessage MsgRGB(0, V_RGB);
MyMessage MsgRGBW(0, V_RGBW);
MyMessage MsgTEXT(0, V_TEXT);

// Debug
#ifdef RS485_DEBUG
  MyMessage MsgCUSTOM(0, V_CUSTOM);
#endif

/**
 * @brief Setups software components: hardware version, configuration, LED controller, wdt reset
 * 
 */
void before() {

  #ifdef ENABLE_WATCHDOG
    wdt_reset();
    MCUSR = 0;
    wdt_disable();
  #endif

  // Resistive hardware detection
  uint16_t ReadHardware = analogRead(HARDWARE_DETECTION_PIN);

  if(ReadHardware < 20) {
    // Hardware variant: 2Relay Board
    HardwareVariant = 0;
  }
  else if(ReadHardware < 40)  {
    // Hardware variant: RGBW Board
    HardwareVariant = 1;
  }
  else  {/* Handling error */}

  // Reading dip switches, determining load variant
  pinMode(DIP_SWITCH_1, INPUT_PULLUP);
  pinMode(DIP_SWITCH_2, INPUT_PULLUP);
  pinMode(DIP_SWITCH_3, INPUT_PULLUP);

  delay(100);

  if(!digitalRead(DIP_SWITCH_1)) {
    // DIP SWITCH 1 ON
    // HardwareVariant 0: roller shutter; HardwareVariant 1: Dimmer 
    LoadVariant = 2;
  }
  else  {
    if(!digitalRead(DIP_SWITCH_2))  {
      // DIP SWITCH 2 ON
      // HardwareVariant 0: single switch; HardwareVariant 1: RGB
      LoadVariant = 0;
    }
    else  {
      // Default option - DIP SWITCH 1 & DIP SWITCH 2 OFF
      // HardwareVariant 0: double switch; HardwareVariant 1: RGBW
      LoadVariant = 1;
    }
  }

  if(!digitalRead(DIP_SWITCH_3)) {
    // Saving States to EEPROM
    // TO BE DEVELOPED
  }

  // Calculating number of iterations depending from IO instances
  Iterations = (HardwareVariant == 0 && LoadVariant == 0) ? 1 : 2;

  // Detecting I2C peripherals
  Wire.begin();
  // TO BE DEVELOPED

  // Support for 400kHz available
  //Wire.setClock(400000UL);

  // Initializing LP5009/LP5012
  LP5009.Begin();
}

/**
 * @brief Setups software components: objects, initialize LEDs, enable wdt
 * 
 */
void setup() {

  // LED: 0 || 1 || 2; R,G,B: 0-255, brightness: 0-255
  // LED0 - D1 (Touch Field A0), LED1 - D3 (Touch Field A2), LED2 - D2 (Touch Field A1)
  // LP5009.SetLEDColor(LED, R, G, B)
  // LP5009.SetLEDBrightness(LED, brightness)

  // LED initialization visual effect
  RainbowLED(RAINBOW_DURATION, RAINBOW_RATE);

  float Vcc = ReadVcc();  // mV

  // Initializing POWER SENSOR
  #if defined(POWER_SENSOR)
    if(HardwareVariant == 0)  {
      PS.SetValues(PS_PIN, MVPERAMP, 230, MAX_CURRENT, POWER_MEASURING_TIME, Vcc);
    }
    else if(HardwareVariant == 1) {
      PS.SetValues(PS_PIN, MVPERAMP, 24, 6, POWER_MEASURING_TIME, Vcc);
    }
  #endif

  // Initializing inputs & outputs
  if(HardwareVariant == 0)  {
    if(LoadVariant == 0)  {
      // Lighting: One button, single output
      CommonIO[RELAY_ID_1].SetValues(RELAY_OFF, false, 6, TOUCH_FIELD_3, INPUT_PIN_1, RELAY_PIN_1);
      // Not used touch field for calibration purposes
      CommonIO[UNUSED_TF_ID].SetValues(RELAY_OFF, false, 5, TOUCH_FIELD_1);
    }
    else if(LoadVariant == 1) {
      // Lighting: two buttons, double output
      CommonIO[RELAY_ID_1].SetValues(RELAY_OFF, false, 6, TOUCH_FIELD_1, INPUT_PIN_1, RELAY_PIN_1);
      CommonIO[RELAY_ID_2].SetValues(RELAY_OFF, false, 6, TOUCH_FIELD_2, INPUT_PIN_2, RELAY_PIN_2);
      // Not used touch field for calibration purposes
      CommonIO[UNUSED_TF_ID].SetValues(RELAY_OFF, false, 5, TOUCH_FIELD_3);
    }
    else if(LoadVariant == 2) {
      // Shutter
      CommonIO[SHUTTER_ID].SetValues(RELAY_OFF, false, 5, TOUCH_FIELD_1);
      CommonIO[SHUTTER_ID + 1].SetValues(RELAY_OFF, false, 5, TOUCH_FIELD_2);
      // Not used touch field for calibration purposes
      CommonIO[UNUSED_TF_ID].SetValues(RELAY_OFF, false, 5, TOUCH_FIELD_3);
      Shutter.SetOutputs(RELAY_OFF, RELAY_PIN_1, RELAY_PIN_2);
      // Temporary calibration (first launch only)
      if(!Shutter.Calibrated) {
        Shutter.Calibration(UP_TIME, DOWN_TIME);
      }
    }
  }
  else if(HardwareVariant == 1) {
    if(LoadVariant == 2)  {
      // 1-channel dimmer
      Dimmer.SetValues(NUMBER_OF_CHANNELS, DIMMING_STEP, DIMMING_INTERVAL, LED_PIN_W);
    }
    else if(LoadVariant == 0) {
      // RGB dimmer
      Dimmer.SetValues(NUMBER_OF_CHANNELS, DIMMING_STEP, DIMMING_INTERVAL, LED_PIN_R, LED_PIN_G, LED_PIN_B);
    }
    else if(LoadVariant == 1) {
      // RGBW dimmer
      Dimmer.SetValues(NUMBER_OF_CHANNELS, DIMMING_STEP, DIMMING_INTERVAL, LED_PIN_R, LED_PIN_G, LED_PIN_B, LED_PIN_W);
    }
    // Every dimmer has two buttons
    CommonIO[0].SetValues(RELAY_OFF, false, 5, TOUCH_FIELD_1);
    CommonIO[1].SetValues(RELAY_OFF, false, 5, TOUCH_FIELD_2);
    // Not used touch field for calibration purposes
    CommonIO[UNUSED_TF_ID].SetValues(RELAY_OFF, false, 5, TOUCH_FIELD_3);
  }

  // Indicate inactivity with LEDs
  for(int i=0; i<Iterations; i++) {
    AdjustLEDs(3, i);
  }

  // ONBOARD THERMOMETER
  #ifdef SHT30
    sht.init();
    sht.setAccuracy(SHTSensor::SHT_ACCURACY_MEDIUM);
  #endif

  // Enable AVR Watchdog
  #ifdef ENABLE_WATCHDOG
    wdt_enable(WDTO_8S);
  #endif

}

/**
 * @brief Presents module to the controller, send name, software version, info about sensors
 * 
 */
void presentation() {

  // OUTPUT
  if(HardwareVariant == 0)  {
    if(LoadVariant == 0)  {
      sendSketchInfo("GWT-2R-1c", SV);
      present(RELAY_ID_1, S_BINARY, "Relay 1");   wait(PRESENTATION_DELAY);
    }
    else if(LoadVariant == 1) {
      sendSketchInfo("GWT-2R-2c", SV);
      present(RELAY_ID_1, S_BINARY, "Relay 1");   wait(PRESENTATION_DELAY);
      present(RELAY_ID_2, S_BINARY, "Relay 2");   wait(PRESENTATION_DELAY);
    }
    else if(LoadVariant == 2) {
      sendSketchInfo("GWT-2R-Shutter", SV);
      present(SHUTTER_ID, S_COVER, "Shutter");  wait(PRESENTATION_DELAY);     
    }
  }
  else if(HardwareVariant == 1) {
    if(LoadVariant == 2)  {
      sendSketchInfo("GWT-D-1c", SV);
      present(DIMMER_ID, S_DIMMER, "Dimmer"); wait(PRESENTATION_DELAY);
    }
    else if(LoadVariant == 0) {
      sendSketchInfo("GWT-D-3c", SV);
      present(DIMMER_ID, S_RGB_LIGHT, "RGB"); wait(PRESENTATION_DELAY);
    }
    else if(LoadVariant == 1) {
      sendSketchInfo("GWT-D-4c", SV);
      present(DIMMER_ID, S_RGBW_LIGHT, "RGBW");   wait(PRESENTATION_DELAY);
    }
  }

  #ifdef SPECIAL_BUTTON
    present(SPECIAL_BUTTON_ID, S_BINARY, "Longpress-1"); wait(PRESENTATION_DELAY);
    present(SPECIAL_BUTTON_ID+1, S_BINARY, "Longpress-2"); wait(PRESENTATION_DELAY);
  #endif

  // POWER SENSOR
  #if defined(POWER_SENSOR)
    present(PS_ID, S_POWER, "Power Sensor");    wait(PRESENTATION_DELAY);
  #endif

  // Onboard Thermometer
  #ifdef SHT30
    present(ETT_ID, S_TEMP, "External Thermometer"); wait(PRESENTATION_DELAY);
    present(ETH_ID, S_HUM, "External Hygrometer");  wait(PRESENTATION_DELAY);
  #endif

  // Electronic fuse
  #ifdef ELECTRONIC_FUSE 
      present(ES_ID, S_BINARY, "OVERCURRENT ERROR");    wait(PRESENTATION_DELAY);
  #endif

  #ifdef SHT30
    present(ETS_ID, S_BINARY, "ET STATUS");   wait(PRESENTATION_DELAY);
  #endif

  #ifdef RS485_DEBUG
    present(DEBUG_ID, S_INFO, "DEBUG INFO");
    present(TOUCH_DIAGNOSTIC_ID, S_CUSTOM, "Touch Diagnostic");
  #endif

  // Configuration sensor
  present(CONFIGURATION_SENSOR_ID, S_INFO, "TEXT MSG");

}

/**
 * @brief Sends initial value of sensors as required by Home Assistant
 * 
 */
void InitConfirmation() {

  // OUTPUT
  // 2Relay
  if(HardwareVariant == 0)  {
    // Single output
    if(LoadVariant == 0)  {
      send(MsgSTATUS.setSensor(RELAY_ID_1).set(CommonIO[RELAY_ID_1].NewState));
      request(RELAY_ID_1, V_STATUS);
      wait(2000, C_SET, V_STATUS);
    }
    // Double output
    else if(LoadVariant == 1) {
      send(MsgSTATUS.setSensor(RELAY_ID_1).set(CommonIO[RELAY_ID_1].NewState));
      request(RELAY_ID_1, V_STATUS);
      wait(2000, C_SET, V_STATUS);

      send(MsgSTATUS.setSensor(RELAY_ID_2).set(CommonIO[RELAY_ID_2].NewState));
      request(RELAY_ID_2, V_STATUS);
      wait(2000, C_SET, V_STATUS);
    }
    // Roller shutter
    else if(LoadVariant == 2) {
      send(MsgUP.setSensor(SHUTTER_ID).set(0));
      request(SHUTTER_ID, V_UP);
      wait(2000, C_SET, V_UP);

      send(MsgDOWN.setSensor(SHUTTER_ID).set(0));
      request(SHUTTER_ID, V_DOWN);
      wait(2000, C_SET, V_DOWN);

      send(MsgSTOP.setSensor(SHUTTER_ID).set(0));
      request(SHUTTER_ID, V_STOP);
      wait(2000, C_SET, V_STOP);

      send(MsgPERCENTAGE.setSensor(SHUTTER_ID).set(Shutter.Position));
      request(SHUTTER_ID, V_PERCENTAGE);
      wait(2000, C_SET, V_PERCENTAGE);
    }
  }
  // RGBW
  else if(HardwareVariant == 1) {
    send(MsgSTATUS.setSensor(DIMMER_ID).set(false));
    request(DIMMER_ID, V_STATUS);
    wait(2000, C_SET, V_STATUS);
    
    send(MsgPERCENTAGE.setSensor(DIMMER_ID).set(Dimmer.NewDimmingLevel));
    request(DIMMER_ID, V_PERCENTAGE);
    wait(2000, C_SET, V_PERCENTAGE);

    // RGB dimmer
    if(LoadVariant == 0)  {
      send(MsgRGB.setSensor(DIMMER_ID).set("ffffff"));
      request(DIMMER_ID, V_RGB);
      wait(2000, C_SET, V_RGB);
    }
    // RGBW dimmer
    else if(LoadVariant == 1) {
      send(MsgRGBW.setSensor(DIMMER_ID).set("ffffffff"));
      request(DIMMER_ID, V_RGBW);
      wait(2000, C_SET, V_RGBW);
    }
    // 1-channel dimmer
    else if(LoadVariant == 2) {}
  }

  #ifdef SPECIAL_BUTTON
    send(MsgSTATUS.setSensor(SPECIAL_BUTTON_ID).set(0));
    send(MsgSTATUS.setSensor(SPECIAL_BUTTON_ID+1).set(0));
  #endif

  // Built-in sensors
  #ifdef POWER_SENSOR
    send(MsgWATT.set("0"));
  #endif

  // External sensors
  #ifdef SHT30
    ETUpdate();
    send(MsgSTATUS.setSensor(ETS_ID).set(0));
  #endif

  //
  #ifdef ELECTRONIC FUSE
    send(MsgSTATUS.setSensor(ES_ID).set(0));
  #endif

  #ifdef RS485_DEBUG
    send(MsgTEXT.setSensor(DEBUG_ID).set("DEBUG MESSAGE"));
    send(MsgCUSTOM.setSensor(TOUCH_DIAGNOSTIC_ID).set(0));
  #endif

  send(MsgTEXT.setSensor(CONFIGURATION_SENSOR_ID).set("CONFIG INIT"));

  SetLEDs();

  InitConfirm = true;

}

/**
 * @brief performs a rainbow effect on active LEDs
 * 
 * @param Duration duration of effect
 * @param Rate rate of effect
 */
void RainbowLED(uint16_t Duration, uint8_t Rate)	{
	
  int RValue = 254;
  int GValue = 127;
  int BValue = 1;
  int RDirection = -1;
  int GDirection = -1;
  int BDirection = 1;
  uint32_t StartTime = millis();
	
  while(millis() < StartTime + Duration)	{

    if(Iterations == 1)  {
      AdjustLEDs2(BUILTIN_LED3, BRIGHTNESS_VALUE_ON, RValue, GValue, BValue);
    }
    else {
      uint8_t LEDs[2] = {BUILTIN_LED1, BUILTIN_LED2};
      for(int i=0; i<Iterations; i++)  {
        AdjustLEDs2(LEDs[i], BRIGHTNESS_VALUE_ON, RValue, GValue, BValue);
      }
    }
	
    RValue += RDirection;
    GValue += GDirection;
    BValue += BDirection;
	
    if(RValue >= 255 || RValue <= 0)	{
      RDirection = -RDirection;
    }
	
    if(GValue >= 255 || GValue <= 0)	{
      GDirection = -GDirection;
    }
	
    if(BValue >= 255 || BValue <= 0)	{
      BDirection = -BDirection;
    }

    if(millis() < StartTime)  {
      StartTime = millis();
    }

    wait(Rate);
  }
}

/**
 * @brief Adjusts built-in LEDs to current state of buttons 
 * 
 * @param State state of button
 * @param Button number of button (ID)
 */
void AdjustLEDs(uint8_t State, uint8_t Button) {

  uint8_t LED;

  if(HardwareVariant == 0 && LoadVariant == 0)  {
    LED = BUILTIN_LED3;
  }
  else  {
    LED = Button == 0 ? BUILTIN_LED1 : BUILTIN_LED2;
  }

  switch(State) {
    case 0:
      // Output is in OFF state
      AdjustLEDs2(LED, BRIGHTNESS_VALUE_OFF,R_VALUE_OFF, G_VALUE_OFF, B_VALUE_OFF);
      break;
    case 1:
      // Output is in ON state
      AdjustLEDs2(LED, BRIGHTNESS_VALUE_ON,R_VALUE_ON, G_VALUE_ON, B_VALUE_ON);
      break;
    case 2:
      // Long press
      RainbowLED(RAINBOW_DURATION, RAINBOW_RATE);
      break;
    case 3:
      // Indication of button inactivity
      AdjustLEDs2(LED, BRIGHTNESS_VALUE_ON, R_VALUE_INACTIVE, G_VALUE_INACTIVE, G_VALUE_INACTIVE);
      break;
    case 4:
      // Turn all channels OFF
      AdjustLEDs2(LED, 0, 0, 0, 0);
      break;
    default:
      break;
  }
}

/**
 * @brief Sets built-in LEDs to given color and brightness
 * 
 * @param LED number of LED
 * @param Brightness brightness value to be set
 * @param R red value to be set
 * @param G green value to be set
 * @param B blue value to be set
 */
void AdjustLEDs2(uint8_t LED, uint8_t Brightness, uint8_t R, uint8_t G, uint8_t B) {

  // LED: BUILTIN_LED1 / BUILTIN_LED2 / BUILTIN_LED3
  LP5009.SetLEDColor(LED, R, G, B);
  LP5009.SetLEDBrightness(LED, Brightness);
}

/**
 * @brief Sets LEDs according to current output state
 */
void SetLEDs()  {

  // Adjust LEDs back to indicate the states of buttons
  if(HardwareVariant == 0)  {
    if(LoadVariant != 2)  {
      for(int i=0; i<Iterations; i++) {
        AdjustLEDs(CommonIO[i].State, i);
      }
    }
    else {
      if(Shutter.State == 2) {
        AdjustLEDs(0, 0); AdjustLEDs(0, 1);
      }
      else if(Shutter.State == 1)  {
        AdjustLEDs(0, 0); AdjustLEDs(1, 1);
      }
      else if(Shutter.State == 0)  {
        AdjustLEDs(1, 0); AdjustLEDs(0, 1);
      }
    }
  }
  else if(HardwareVariant == 1) {
    if(Dimmer.CurrentState) {
      AdjustLEDs(1, 0); AdjustLEDs(0, 1);
    }
    else  {
      AdjustLEDs(0, 0); AdjustLEDs(0, 1);
    }
  }
}

/**
 * @brief Blinks built-in LEDs with externally controlled period
 * 
 * @param InitialState initial state of function
 */
void BlinkLEDs(uint8_t InitialState=0) {
  
  static uint8_t Blink = 3;

  if(InitialState == 3 || InitialState == 4) {
    Blink = InitialState;
  }

  for(int i=0; i<Iterations; i++) {
    AdjustLEDs(Blink, i);
  }

  Blink = Blink == 3 ? 4 : 3;
}

/**
 * @brief Diagnoses the operation of touch buttons
 * 
 * @param Threshold touch treshold value from Configuration.h
 */
void TouchDiagnosis(uint16_t Threshold) {

  for(int i=0; i<Iterations; i++)  {
    if(CommonIO[i].TouchDiagnosisValue > (int)(Threshold / 2) || CommonIO[i].TouchDiagnosisValue < -(int)(Threshold / 2))  {
      
      #ifdef RS485_DEBUG
        // Send message with TouchValue
        send(MsgCUSTOM.setSensor(TOUCH_DIAGNOSTIC_ID).set(IO[i].TouchDiagnosisValue));
      #endif

      if(CommonIO[i].TouchDiagnosisValue < Threshold) {
        LimitTransgressions++;
      }
    }
  }
}

/**
 * @brief Diagnoses the operation of touch buttons
 * 
 */
void TouchDiagnosis2() {

  for(int i=0; i<2; i++)  {
    CommonIO[UNUSED_TF_ID].CheckInput2(TOUCH_THRESHOLD, LONGPRESS_DURATION, DEBOUNCE_VALUE);
    if(CommonIO[UNUSED_TF_ID].NewState < 2) return;
  }
  
  CommonIO[UNUSED_TF_ID].NewState = 0;
  ReadNewReference();
}

/**
 * @brief Reads new reference value for touch buttons
 * 
 */
void ReadNewReference() {

  if(HardwareVariant == 0 && LoadVariant == 2)  {
    Shutter.NewState = 2;
    Shutter.Movement();
  }

  // Blink LEDs to indicate inactivity and take a break from normal operation
  for(int i=0; i<5; i++)  {
    BlinkLEDs();
    delay(1000);
  }

  // Read new reference
  for(int i=0; i<Iterations+1; i++)  {
    CommonIO[i].ReadReference();
  }

  // Rainbow LED visual effect - indicate calibration
  RainbowLED(RAINBOW_DURATION, RAINBOW_RATE);

  // Adjust LEDs to indicate button states
  SetLEDs();
}
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
void loop() {

  float Vcc = ReadVcc(); // mV
  float Current = 0;

  // Sending out states for the first time (as required by Home Assistant)
  if (!InitConfirm)  {
    InitConfirmation();
  }

  // Reading power sensor
  #ifdef POWER_SENSOR
    // 2Relay Board
    if(HardwareVariant == 0)  {
      if (digitalRead(RELAY_PIN_1) == RELAY_ON || digitalRead(RELAY_PIN_2) == RELAY_ON)  {
        Current = PS.MeasureAC(Vcc);
      }
    }
    // RGBW Board
    if(HardwareVariant == 1)  {
      if (Dimmer.CurrentState)  {
        Current = PS.MeasureDC(Vcc);
      }
    }

    PSUpdate(Current);
      
    #ifdef ERROR_REPORTING
      OVERCURRENT_ERROR = PS.ElectricalStatus(Current);
    #endif
  #endif

  // Current safety
  #if defined(ELECTRONIC_FUSE) && defined(POWER_SENSOR)
    if(OVERCURRENT_ERROR)  {
      // Current to high
      // Board: 2Relay 
      if(HardwareVariant == 0)  {
        // Load: Lighting
        if(LoadVariant < 2) {
          for (int i = RELAY_ID_1; i < RELAY_ID_1 + NUMBER_OF_RELAYS; i++)  {
            CommonIO[i].SetState(RELAY_OFF);
            CommonIO[i].SetRelay();
            send(MsgSTATUS.setSensor(i).set(RELAY_OFF));
          }
        }
        // Load: Roller shutter
        else if(LoadVariant == 2) {
          Shutter.NewState = 2;
          ShutterUpdate(0);
        }
      }
      // Board: RGBW
      else if(HardwareVariant == 1) {
        Dimmer.ChangeState(false);
        send(MsgSTATUS.setSensor(DIMMER_ID).set(Dimmer.CurrentState));
      }
      send(MsgSTATUS.setSensor(ES_ID).set(OVERCURRENT_ERROR));
      InformControllerES = true;
    }
    else if(!OVERCURRENT_ERROR && InformControllerES)  {
      // Current normal (only after reporting error)
      send(MsgSTATUS.setSensor(ES_ID).set(OVERCURRENT_ERROR));
      InformControllerES = false;
    }
  #endif

    // Reading inputs & adjusting outputs
  if(Iterations > 0)  {
    UpdateIO();
    if(LongpressDetection > 0)  {
      
      // Launch Longpress LED sequence
      AdjustLEDs(2, 0);

      // Adjust LEDs back to indicate the states of outputs
      SetLEDs();

      LongpressDetection = 0;
      
      #ifdef SPECIAL_BUTTON
        for(int i=SPECIAL_BUTTON_ID; i<SPECIAL_BUTTON_ID+2; i++)  {
          send(MsgSTATUS.setSensor(i).set(false));
        }
      #endif  
    }
    if(HardwareVariant == 0 && LoadVariant == 2)  {
      ShutterUpdate(Current);
    }
    else if(HardwareVariant == 1)  {
      Dimmer.UpdateDimmer();
    }
  }

  // Reset LastUpdate if millis() has overflowed
  if(LastUpdate > millis()) {
    LastUpdate = millis();
  }

  #ifdef TOUCH_AUTO_DIAGNOSTICS
    // Checking if touch feature works correctly
    TouchDiagnosis2();
  #endif
  
  // Checking out sensors which report at a defined interval
  if ((millis() > LastUpdate + INTERVAL) || CheckNow == true)  {
    #ifdef SHT30
      ETUpdate();
    #elif defined(POWER_SENSOR)
      PSUpdate(Current);
    #endif

    LimitTransgressions = 0;
    LastUpdate = millis();
    CheckNow = false;
  }

  wait(LOOP_TIME);
}
/*

   EOF

*/

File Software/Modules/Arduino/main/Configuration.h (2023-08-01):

/*
 * Configuration.h file
 * Use this file for quick and easy configuration of your GetWired software.
 * For the whole description have a look at .ino file.
 * 
 */

#ifndef Configuration_h
#define Configuration_h

/***** Protocol Definitions *****/
// Identification
#define MY_NODE_ID AUTO                       // Set node ID
#define SN "GoWired Module"                   // Set node name to present to a controller
#define SV "2.1"                            // Set sensor version

// Selecting transmission settings
#define MY_RS485                              // Enable RS485 transport layer
#define MY_RS485_DE_PIN 7                     // DE Pin definition
#define MY_RS485_BAUD_RATE 57600              // Set RS485 baud rate
#define MY_RS485_HWSERIAL Serial              // Enable Hardware Serial
#define MY_RS485_SOH_COUNT 3                  // Collision avoidance

// FOTA Feature
#define MY_OTA_FIRMWARE_FEATURE                 // Enable OTA feature

// Other
#define MY_TRANSPORT_WAIT_READY_MS 60000        // Time to wait for gateway to respond at startup (default 60000)

/***** Quick Config *****/
// Output Config - one of these has to be defined
#define DOUBLE_RELAY              // Define this node as a double relay node, setting below
//#define ROLLER_SHUTTER            // Define this node as a roller shutter node, setting below
//#define FOUR_RELAY                // Define this node as a four relay node, setting below
//#define DIMMER                    // Define this node as a 1-channel dimmer node, setting below
//#define RGB                       // Define this node as a RGB dimmer node, setting below
//#define RGBW                      // Define this node as a RGBW dimmer node, setting below

// Input Config - define according to your needs
// Digital Inputs
#define INPUT_1
#define INPUT_2
#define INPUT_3
#define INPUT_4

// Board dependent
#define POWER_SENSOR
#define INTERNAL_TEMP

// External temperature sensor - define DHT22 or SHT30
//#define EXTERNAL_TEMP
#ifdef EXTERNAL_TEMP
    //#define DHT22
    #define SHT30
#endif

/***** Pin Definitions *****/
// OUTPUT [RELAY / RGBW]
#define OUTPUT_PIN_1 5
#define OUTPUT_PIN_2 9
#define OUTPUT_PIN_3 6
#define OUTPUT_PIN_4 10

// INPUT [BUTTON / SENSOR]
// General input
#define INPUT_PIN_1 2             // default 2
#define INPUT_PIN_2 3             // default 3
#define INPUT_PIN_3 4             // default 4
#define INPUT_PIN_4 A3              // default A3

// Analog input
#define INPUT_PIN_5 A1              // default A1
#define INPUT_PIN_6 A2              // default A2
#define INPUT_PIN_7 A6              // default A6
#define INPUT_PIN_8 A7              // default A7

// Protocols
// 1-wire
#define ONE_WIRE_PIN A0             // default A0

// I2C
#define I2C_PIN_1 A4              // default A4
#define I2C_PIN_2 A5              // default A5

/***** Various Definitions *****/
// General
#define RELAY_ON HIGH                       // Pin state to turn the relays on (default HIGH)
#define RELAY_OFF LOW                       // Pin state to turn the relays off (default LOW)
#define LONGPRESS_DURATION 1000
#define DEBOUNCE_VALUE 50

// Internal temperature sensor
#define MVPERC 10                         // V per 1 degree celsius (default 10)
#define ZEROVOLTAGE 500                     // Voltage output of temperature sensor (default 500)
#define MAX_TEMPERATURE 85                  // Maximum temperature the module can have before reporting error (default 85)

// Power Sensor
#define MAX_CURRENT 3                      // Maximum current the module can handle before reporting error (2SSR - 3; 4RelayDin - 10A or 16)
#define POWER_MEASURING_TIME 20             // Current measuring takes this long (default 20)
#define MVPERAMP 185                       // mV per 1A (default: 2SSR 185 mV/A; 4RelayDin 73.3 mV/A, RGBW 100 mV/A)
#define RECEIVER_VOLTAGE 230                // 230V, 24V, 12V - values for power usage calculation, depends on the receiver
#define COSFI 1                             // cos(fi) value for a given load: resistive load - 1, LED - 0.4 < cos(fi) < 0.99, fluorescent - 

// Dimmer
#define DIMMING_STEP 1                      // Size of dimming step, increase for faster, less smooth dimming (default 1)
#define DIMMING_INTERVAL 1                  // Duration of dimming interval, increase for slower dimming (default 10)
#define DIMMING_TOGGLE_STEP 20              // Value to increase dimming percentage when using wall switch

// Roller Shutter 
#define PS_OFFSET 0.2                     // Power sensor offset for roller shutter calibration (default 0.2)
#define CALIBRATION_SAMPLES 1             // Number of calibration samples for roller shutter calibration (default 2)
#define UP_TIME 21                        // Manually defined upward movement time in seconds (0-255)
#define DOWN_TIME 20                      // Manually defined downward movement time in seconds (0-255)
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

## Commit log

2019-05-29 New firmware on the way
    [Configuration.h]
2019-07-12 More new files
    [Configuration_ASUS_lip-08-113526-2019_Conflict.h]
2019-09-11 Bug fixes
    [Configuration.h]
2019-09-16 Heating Controller
    [Configuration.h]
2019-11-06 Rename RS485 Heating Controller/main.ino to GetWired Heating Controller/main.ino
2019-11-06 Rename GetWired Heating Controller/main.ino to RS485 Heating Controller/main.ino
2020-08-10 Rename BOM_Adapter GetWired v1b produkcyjna.csv to BOM GetWired Adapter v1.csv
    [BOM GetWired Adapter v1.csv]
2020-08-10 Rename PnP_Adapter GetWired v1b produkcyjna_back.csv to PnP GetWired Adapter v1.csv
    [PnP GetWired Adapter v1.csv]
2020-08-12 Newest firmware
    [Configuration.h]
2020-08-20 Fixes to RS autocalibration & dimmer overcurrent
    [main.ino]
2020-08-25 Fixes to handling inputs
    [Configuration.h]
2020-08-27 New Features
    [Configuration.h]
2020-08-27 Minor improvements
    [Configuration.h]
2020-10-05 New Heating Controller software
    [Configuration.h]
2020-10-05 New DIN rail enclosure
    Enables mounting in-wall shields (2SSR, RGBW) on TH35 rail.
    [In-Wall-to-DIN_bot.stl, In-Wall-to-DIN_top.stl]
2020-10-09 Presentation delay
    Fixing issue with incorrect node presentation
    [Configuration.h]
2020-10-12 File name fix
    [Configuration.h]
2020-10-14 Updates to Heating Controller
    [Configuration.h]
2020-10-22 Init Confirmation fix
    Fixes a bug causing repetitive calling of InitConfirmation() function in case when no output configured
    [main.ino]
2020-10-22 Gateway restart fix
    Using restart button now does not restart modules connected to the gateway
    [Gateway-MQTT.ino, Gateway.ino]
2021-05-20 Add AVR watchdog, fix roller shutter bug
    [Configuration.h]
2021-06-08 Rewrite roller shutter operation & other changes
    - Roller shutter is now a state machine
    - No while loops in roller shutter regular operation
    - Current measurement during roller shutter movement
    - Roller shutter now reports directions of movement to the controller
    - Changes to safety procedures (thermal & electrical software fuses) and to entire main loop
    - Small improvements
    [Configuration.h]
2021-06-10 Bugfix
    Fix bugs related to millis() overflow
    [main.ino]
2021-07-13 Rename GetWired Heating Controller/Configuration.h to Heating Controller/Configuration.h
    [Configuration.h]
2021-07-13 Rename Heating Controller/Configuration.h to Software/Heating Controller/Configuration.h
    [Configuration.h]
2021-07-13 Rename GetWired Heating Controller/main.ino to Software/Heating Controller/main/main.ino
2021-07-13 Rename Software/Heating Controller/Configuration.h to Software/Heating Controller/main/Configuration.h
    [Configuration.h]
2021-07-13 Rename GetWired Heating Controller/Heating.cpp to Software/Heating Controller/main/Heating.cpp
2021-07-13 Rename GetWired Heating Controller/Heating.h to Software/Heating Controller/main/Heating.h
2021-07-13 Rename GetWired New Firmware/Configuration.h to Software/Modules/main/Configuration.h
    [Configuration.h]
2021-07-13 Rename GetWired New Firmware/PowerSensor.cpp to Software/Modules/main/PowerSensor.cpp
2021-07-13 Rename GetWired New Firmware/PowerSensor.h to Software/Modules/main/PowerSensor.h
2021-07-13 Add description to Heating Controller software
2021-07-16 Add custom indication handler
    [Configuration.h]
2021-07-19 Changes to uplink check & minor changes
    [Configuration.h]
2021-07-28 Reorganize folders
    [Configuration.h]
2021-12-31 Add 8RelayDin software
    [Configuration.h]
2022-01-24 Relocating Multiprotocol Gateway files
    [Configuration.h]
2022-04-04 Changes to dimmer operation
    [Configuration.h]
2022-04-07 8RelayDin fixes
    Fix independent IOs, fix INPUT_TYPE issue
    [Configuration.h]
2022-04-14 Improvements to 8RelayDin
    Better operation with security sensors, possibility of inverting input logic, other minor changes
    [Configuration.h]
2022-04-14 Add roller shutter calibration by message feature
    [Configuration.h]
2022-04-20 Bugfix for 8RelayDin
    [Configuration.h]
2022-04-20 Modules software reading inputs bugfix
    [Configuration.h]
2022-04-27 Move GoWired-Touch software to GoWired-Project repo
    [Configuration.h]
2022-04-27 Adjust Heating Controller software, add some documentation and wdt
    [Configuration.h]
2022-04-29 Adjust Shutters library & Modules main.ino
    [Configuration.h]
2022-05-09 Adjust software to work with GoWired-lib
    [Configuration.h]
2022-05-25 Change configuration by message to work on V_TEXT message type
    [Configuration.h]
2022-06-06 Fix CommonIO bug, add dependencies to library properties
    [main.ino]
2022-06-15 Add configuration sensor to configure modules with text messages
    This feature can use notify.mysensors service in Home Assistant. First working command is "cmd1" which induces shutter calibration.
2022-07-19 Rename some files
    [BOM GoWired Adapter v1.csv, GoWired DIN Rail Case bottom.stl, GoWired DIN Rail Case top.stl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]
2022-07-19 Modify Heating Controller software to work with GoWired-lib
2023-01-23 Update version
    [Configuration.h]
2023-01-23 Add second Longpress; in Touch change order of handling longpress
    [Configuration.h]
2023-01-24 Refactor and changes to reporting power sensor values
    Report changes bigger than 100 mA (Modules&Touch); report periodically redardless of value (Touch)
2023-01-24 Turn relay off if shutter is not moving
    Modules & Touch
2023-06-23 Add touch fields calibration by message feature
    [Configuration.h]
2023-06-23 Add roller shutter stopping before touch field calibration
2023-06-26 New feature: utilize unused touch field for buttons calibration
    Change some special button (long press) logic; special buttons now send false after 100 ms
    [Configuration.h]
2023-07-04 Bugfixes and new message for text sensor
    Type 'cmd4' to erase EEPROM and restart the module
    [Configuration.h]
2023-07-05 Adjust Modules code to recent Touch mods
    Additional options for configuration by message and changes to roller shutter operation
    [Configuration.h]
2023-08-01 Update firmware version in Configuration.h
    [Configuration.h]

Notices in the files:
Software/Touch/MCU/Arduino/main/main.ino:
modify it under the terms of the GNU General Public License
